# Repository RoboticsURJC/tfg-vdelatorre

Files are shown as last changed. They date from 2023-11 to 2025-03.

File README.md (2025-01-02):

# Repositorio de trabajo del TFG
# Víctor de la Torre Rosa

Como primera idea, este TFG estará enfocado a diseñar un prototipo de un
robot que pueda localizarse en interiores y que sea controlado por comandos por voz con el uso de una raspberry a un coste relativamente bajo.

## Material necesario:

[Raspberry PI 4 modelo B](https://www.amazon.es/Raspberry-Modelo-Cortex-A72-1-50GHz-Bluetooth/dp/B0CJ4XHZ4G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)  

[Micrófono micro USB](https://www.amazon.es/gp/product/B08BHM9VVW/ref=ox_sc_act_title_1?smid=A19HXCV96LJNAY&psc=1)

[Tarjeta micro SD](https://es.aliexpress.com/item/1005007985763599.html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)

[Controlador driver l298n](https://www.amazon.es/OcioDual-Controlador-Motores-Driver-Stepper/dp/B07YNR5KWP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)

[Rueda loca](https://www.planetaelectronico.com/rueda-loca-para-robot-diy-p-16998.html)

[Filamento PLA+ 1.75mm](https://www.amazon.es/SUNLU-PLA-3D-1-75mm-dimensional/dp/B07W47D4YZ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)

[Magnetómetro mpu9250](https://es.aliexpress.com/item/1005006375372078.html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)

[Batería recargable](https://www.amazon.es/Gecoty%C2%AE-Bater%C3%ADa-recargable-2400mAh-Conector/dp/B091232MQT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)

[Power Bank](https://www.amazon.es/SLuB-12000mAh-Bateria-Pantalla-Alimentaci%C3%B3n/dp/B0B4RWNZY3?th=1)

[Ruedas y motores reductores](https://www.amazon.es/HeyNana-Ruedas-Motores-Reductor-Coche/dp/B07LDP1DP9?th=1)

En cuanto al entorno de programación, la Raspberry tiene por defecto 
instalado Thonny Python IDE el cual es para proyectos más simples y tiene menos
capacidades que Python 3(IDLE), el cual es más conveniente para este tipo de 
proyectos. Para instalarlo:

```
sudo apt install python3 idle3
``` 

Revisar la [wiki](https://github.com/RoboticsURJC/tfg-vdelatorre/wiki) para más información sobre el proyecto.

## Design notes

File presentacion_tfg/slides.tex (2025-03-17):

% Completa los datos convenientemente en las zonas marcadas con TODO

\documentclass{beamer}
%PARA VISUALIZAR PRESENTACIONN CON NOTAS USAR VISUALIZADOR "pdfpc":
%Para ver las notas, el cronometro y siguente diapo:
% pdfpc --notes=right slides.pdf
% "tecla p": para pausar el cronometro
\mode<presentation> {
  \usetheme{CambridgeUS}
  \usecolortheme{crane} % color naranja
}
\setbeamercolor{titlelike}{parent=structure,bg=yellow!85!orange} % Cambia el color de la caja del título de la página inicial

\setbeamertemplate{navigation symbols}{} % ocultar iconos de navegación
\setbeamerfont{subsection in toc}{size=\small} % reducir tamaño en TOC
\setbeamerfont{date}{size=\tiny}
\usepackage[spanish]{babel}
\usepackage[utf8]{inputenc}
\usepackage{graphicx}
\usepackage{booktabs}
\usepackage{hyperref}
\usepackage{multicol}
\usepackage{pgfpages}
\usepackage{listings}
\usepackage{multimedia}
\usepackage[export]{adjustbox}
\usepackage{outlines} % Para poner bullets tabulados (\1 \2 \3 ...) y no items
\usepackage{fontawesome5} 
\usepackage{array,tabularx} % para tabular leyenda de ecuaciones
\newenvironment{conditions*} % entorno de "leyenda de ecuación"
  {\par\vspace{\abovedisplayskip}\noindent
   \tabularx{\columnwidth}{>{$}l<{$} @{\ : } >{\raggedright\arraybackslash}X}}
  {\endtabularx\par\vspace{\belowdisplayskip}}
  
% USO DE NOTAS
\setbeameroption{hide notes} % Para mostrar u ocultar (hide/show)
%\setbeameroption{show only notes} % Mostrar solo las notas
%\setbeameroption{show notes on second screen=right} % Mostrar notas en otra pantalla
\setbeamertemplate{note page}{ % asi solo muestro el texto de las notas
  \insertnote%
}

%========= TODO: datos internos del documento
\hypersetup{
	pdftitle={Defensa de trabajo de fin de grado de Pon tu nombre},
	pdfauthor={Pon tu nombre},
	pdfsubject={Pon aquí el título completo del trabajo},
	pdfkeywords={teaching, robotics, vision, sensors, actuators, raspberry},
	pdfproducer={pdfLaTeX},
  colorlinks=true,
  linkcolor=blue
}
%=========

%========= TODO: diapositiva de portada
\title[Robot de bajo coste guiado por voz]{Prototipo de robot de bajo coste guiado por voz con técnicas de localización} % El título reducido aparece en la parte inferior de todas las diapositivas
                                         % El título completo aparece solo en la diapositiva de portada
\author[Víctor de la Torre Rosa]{Víctor de la Torre Rosa}
\institute[URJC]
{
\textit{\href{mailto:escribe.tu@correo.es}{\color{blue}{\underline{v.delatorre.2019@alumnos.urjc.es}}}}\\
\vspace{0.5cm}
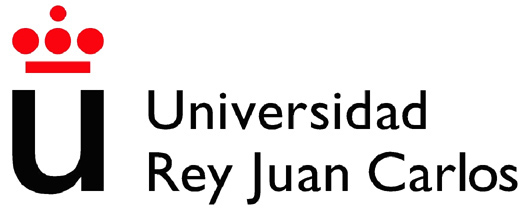
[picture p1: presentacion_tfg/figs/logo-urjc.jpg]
\\
\vspace{1cm}
Trabajo Fin de Grado
}
\date{18 de marzo de 2025}
%=========

%========= COMIENZO DEL DOCUMENTO
\begin{document}

%========= Portada inicial con notas
\begin{frame}[plain] % plain: quita header y footer
\large{\titlepage}
\note[item]{En esta presentación voy a hablar sobre...}
\note[item]{En primer lugar...}
\end{frame}

%========= Licencia
\begin{frame}
\input{licencia.tex}
\end{frame}

%========= Índice o tabla de contenidos (TOC)
\begin{frame}
\frametitle{Contenidos}
\begin{multicols}{2} % si tengo muchas secciones, lo parte en dos columnas
  \tableofcontents[hideallsubsections] % no muestra subsecciones
\end{multicols}
\note[item]{La presentaci\'on esta dividida en cuatro partes.}
\end{frame}

%========= Diapositiva "vacía" de comienzo de sección:
\section*{}
\begin{frame}{}
  \centering \Huge
  \emph{Introducción}
\note[item]{Comencemos con la introducción.}
\end{frame}

\section{Introducción}
\subsection{Contexto general}
%========= Diapositiva con imágenes:
\begin{frame}
\frametitle{Robótica móvil}
\centering
\begin{minipage}{0.45\textwidth}
    \centering
    
\end{minipage}
\hfill
\begin{minipage}{0.45\textwidth}
    \centering
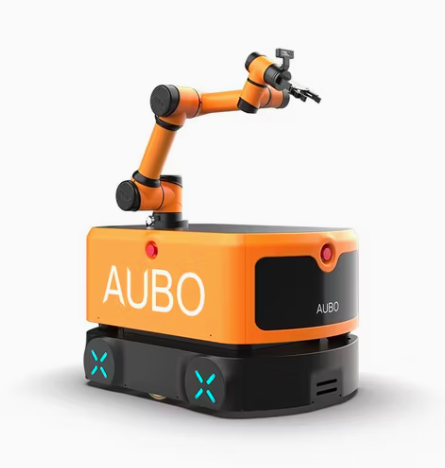
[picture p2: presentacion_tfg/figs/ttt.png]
    
\end{minipage}
\end{frame}

%========= Diapositiva con ítems resaltados con colores:
\begin{frame}
\frametitle{Robótica educativa y de bajo coste}
\centering

% Primera fila
\begin{minipage}{0.45\textwidth}
    \centering
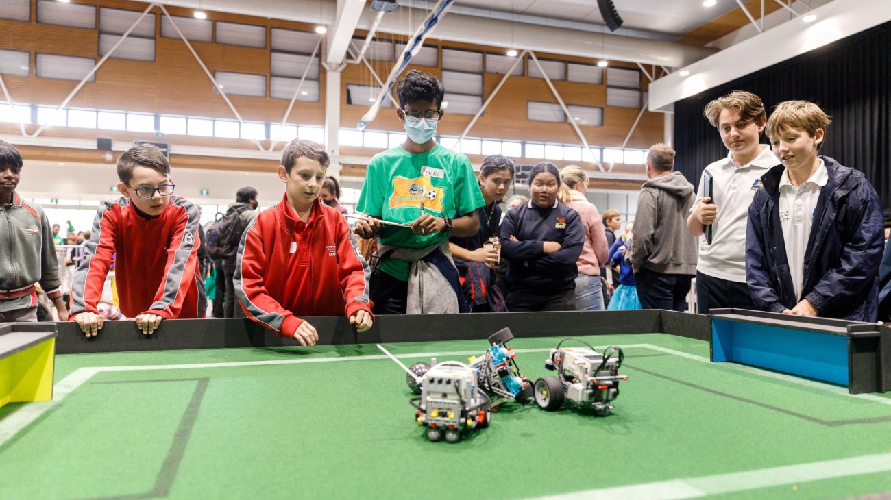
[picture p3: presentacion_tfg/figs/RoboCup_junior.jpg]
    
\end{minipage}
\hfill
\begin{minipage}{0.45\textwidth}
    \centering
    
\end{minipage}

\vspace{0.5cm} % Espacio entre filas

% Segunda fila
\begin{minipage}{0.45\textwidth}
    \centering
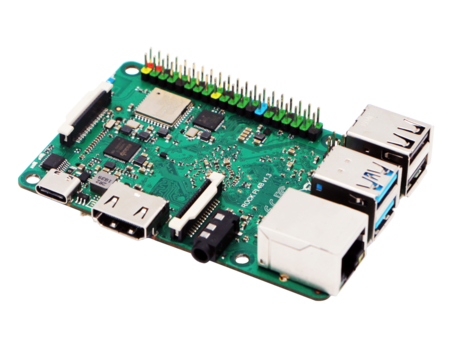
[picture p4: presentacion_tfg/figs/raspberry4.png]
     % Cambia por la ruta de la tercera imagen
\end{minipage}
\hfill
\begin{minipage}{0.45\textwidth}
    \centering
     % Cambia por la ruta de la cuarta imagen
\end{minipage}

\end{frame}

\section*{}
\begin{frame}{}
  \centering \Huge
  \emph{Objetivos}
\note[item]{Pasemos ahora a comentar los objetivos que nos hemos con este trabajo.}
\end{frame}

\section{Objetivos}
\begin{frame}
\frametitle{Descripción del problema}
\centering

% Primera fila
\begin{minipage}{0.45\textwidth}
    \centering
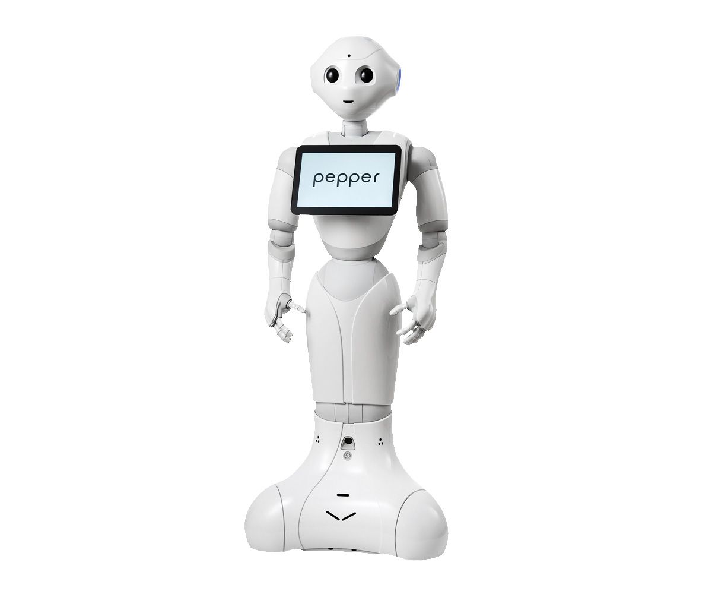
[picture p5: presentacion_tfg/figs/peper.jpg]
    
\end{minipage}
\hfill
\begin{minipage}{0.45\textwidth}
    \centering
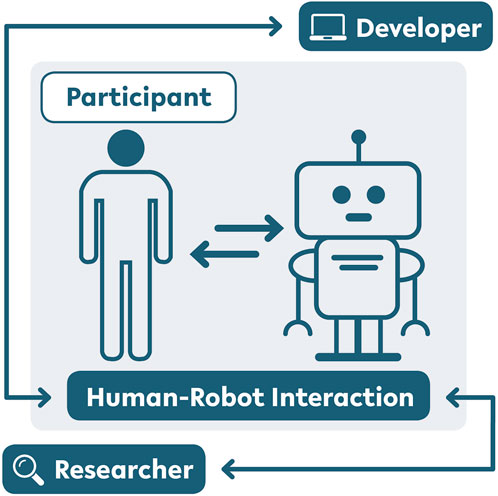
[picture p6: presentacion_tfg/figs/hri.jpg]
    
\end{minipage}

\vspace{0.5cm} % Espacio entre filas

% Segunda fila
\begin{minipage}{0.45\textwidth}
    \centering
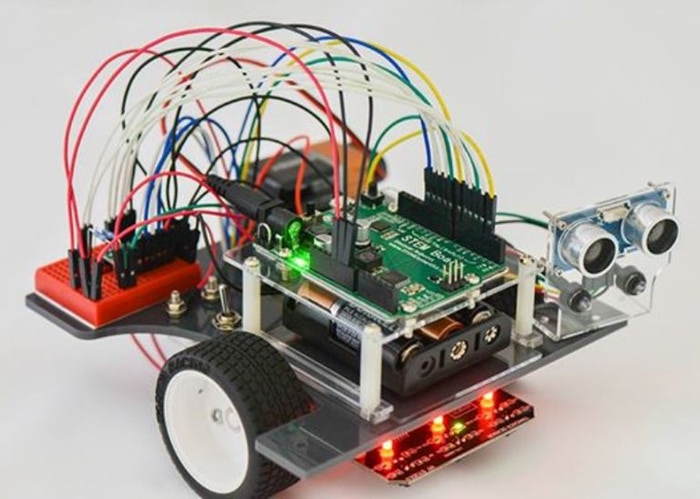
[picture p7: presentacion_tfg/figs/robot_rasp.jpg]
     % Cambia por la ruta de la tercera imagen
\end{minipage}
\hfill
\begin{minipage}{0.45\textwidth}
    \centering
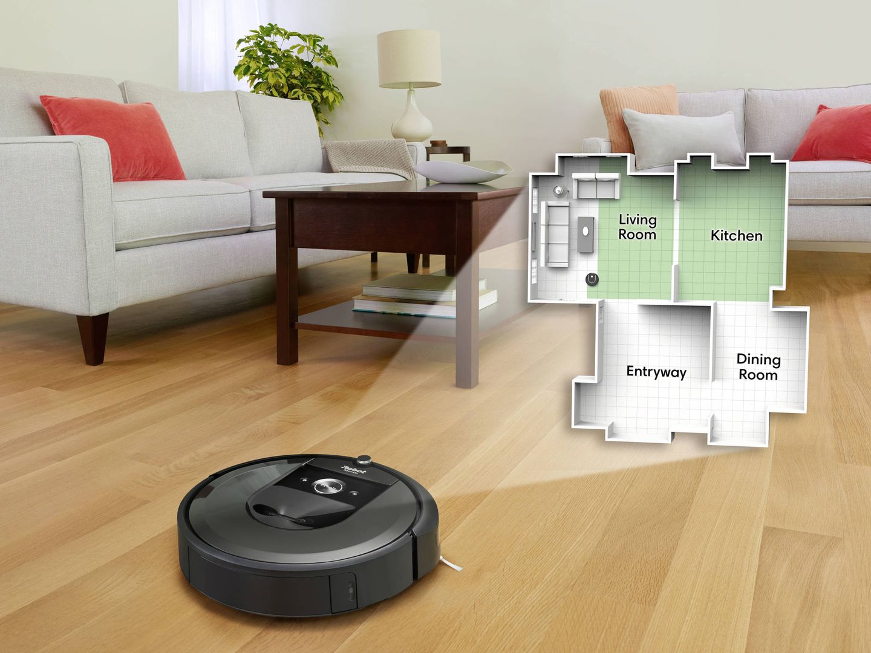
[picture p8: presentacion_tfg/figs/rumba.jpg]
     % Cambia por la ruta de la cuarta imagen
\end{minipage}

\end{frame}

\begin{frame}
\frametitle{Requisitos}
\begin{enumerate}
    \item 145€.
    \item \faDollarSign
    \item \faWifi % Ícono de Wi-Fi en lugar de texto
    \item Impresora convencional 3D.
    \item Tiempo real.
    \item Python.
    \item Batería recargable.
    \item Peso ligero.
\end{enumerate}
\end{frame}

\begin{frame}
\frametitle{Objetivos específicos}
\begin{enumerate}
\item Diseño.
\item Estado del arte.
\item Control del robot.
\item Navegación + Localización.
\item Calibración.
\item Red neuronal.
\end{enumerate}
\end{frame}

\begin{frame}
\frametitle{Metodología}
\centering
\begin{minipage}{0.45\textwidth}
    \centering
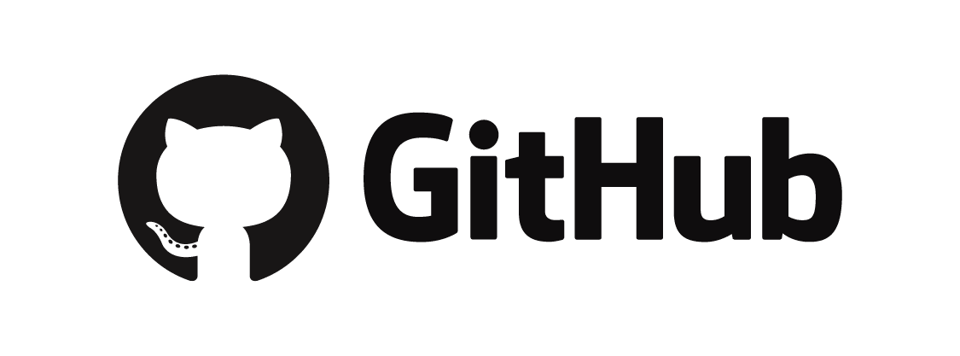
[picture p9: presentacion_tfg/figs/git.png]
    
\end{minipage}
\hfill
\begin{minipage}{0.45\textwidth}
    \centering
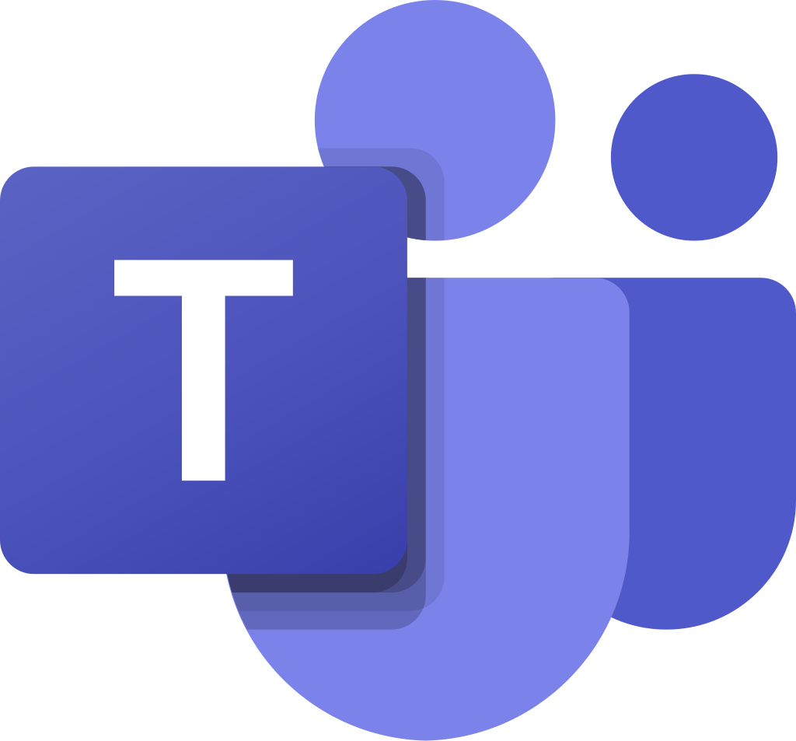
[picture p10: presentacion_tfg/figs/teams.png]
    
\end{minipage}
\vfill

\href{https://github.com/RoboticsURJC/tfg-vdelatorre}{https://github.com/RoboticsURJC/tfg-vdelatorre}
\end{frame}

\section*{}
\begin{frame}{}
  \centering \Huge
  \emph{Plataforma de desarrollo}
\note[item]{Una vez descritos los objetivos, veamos qué hemos hecho para alcanzarlos.}
\end{frame}

\section{Plataforma de desarrollo}
\begin{frame}
\frametitle{Hardware}
\centering

% Primera fila
\begin{minipage}{0.3\textwidth}
    \centering
    
\end{minipage}
\hfill
\begin{minipage}{0.3\textwidth}
    \centering
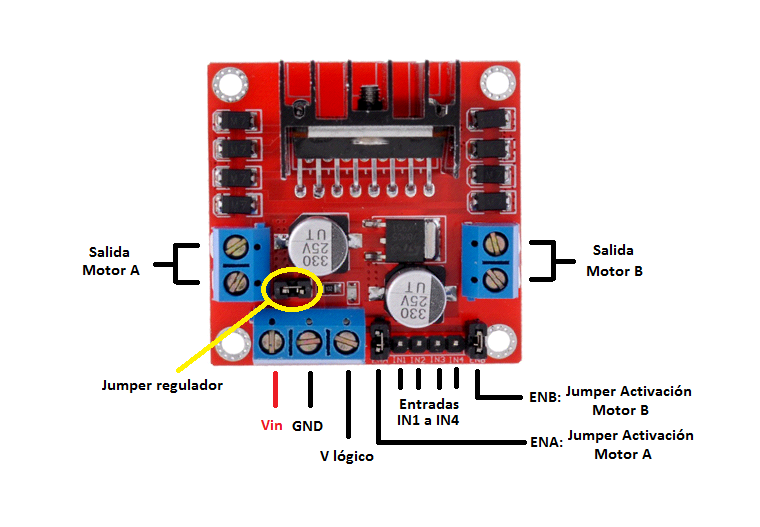
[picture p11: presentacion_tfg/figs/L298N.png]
    
\end{minipage}
\hfill
\begin{minipage}{0.3\textwidth}
    \centering
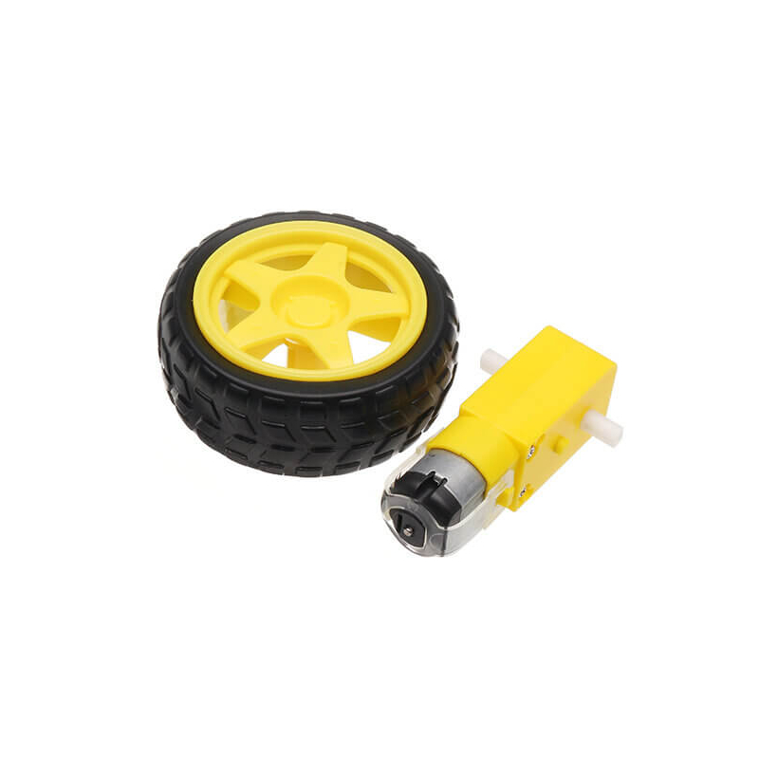
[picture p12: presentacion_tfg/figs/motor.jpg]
    
\end{minipage}

\vspace{-0.3cm} % Reduce el espacio entre filas

% Segunda fila
\begin{minipage}{0.3\textwidth}
    \centering
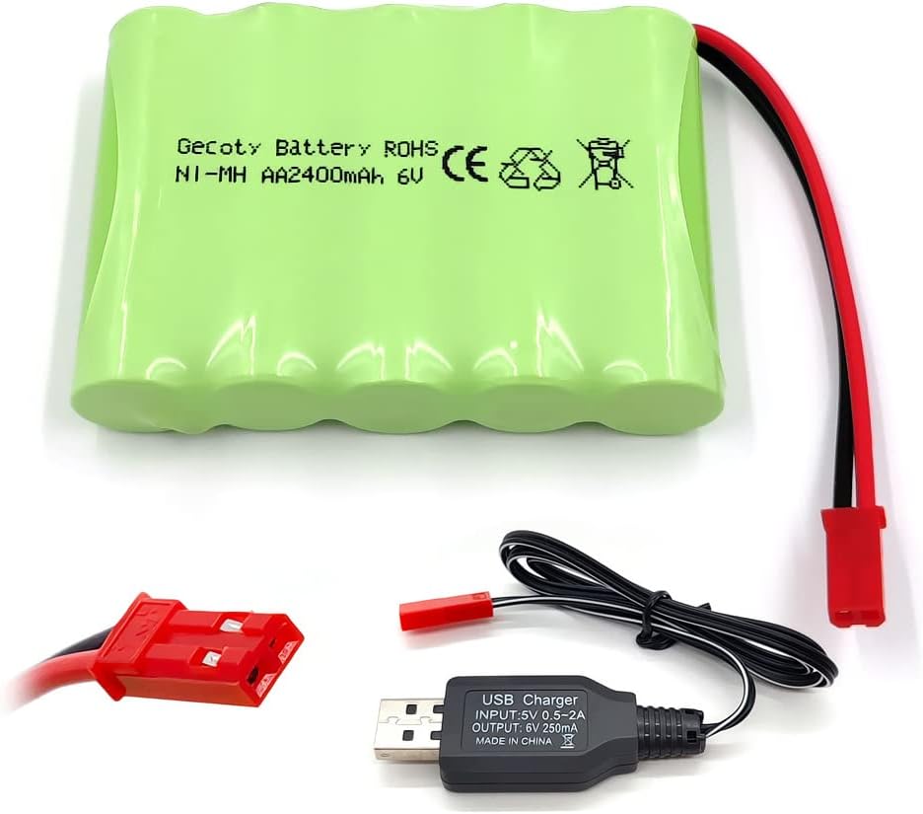
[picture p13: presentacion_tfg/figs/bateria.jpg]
     
\end{minipage}
\hfill
\begin{minipage}{0.3\textwidth}
    \centering
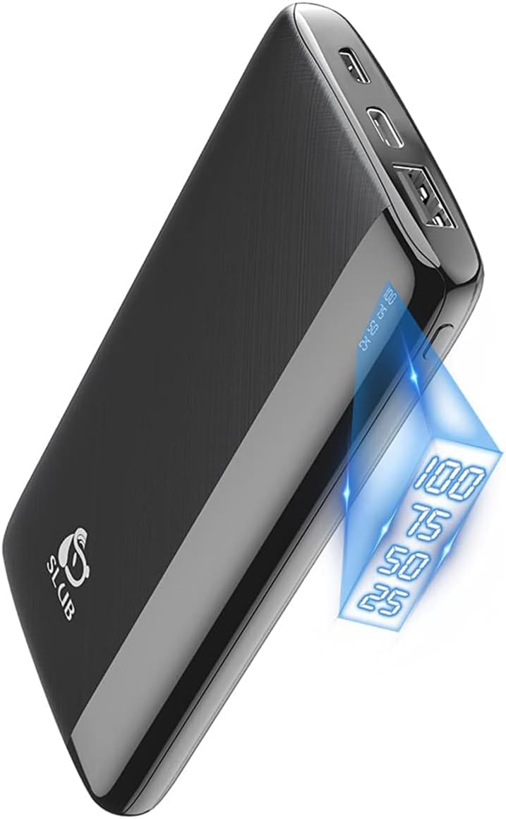
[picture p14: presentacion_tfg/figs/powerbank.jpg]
     
\end{minipage}
\hfill
\begin{minipage}{0.3\textwidth}
    \centering
    
\end{minipage}

% Tercera fila
\begin{minipage}{0.3\textwidth}
    \centering
     
\end{minipage}
\hfill
\begin{minipage}{0.3\textwidth}
    \centering
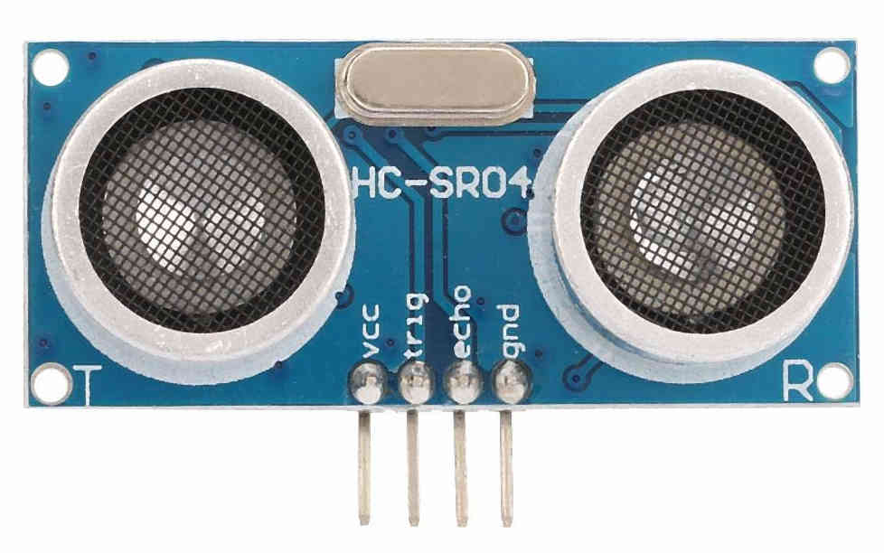
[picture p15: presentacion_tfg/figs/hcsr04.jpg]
     
\end{minipage}
\hfill
\begin{minipage}{0.3\textwidth}
    \centering
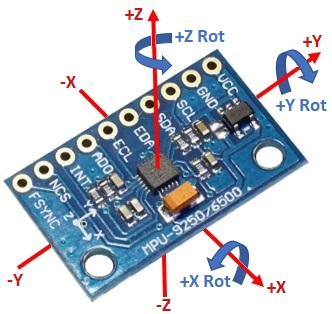
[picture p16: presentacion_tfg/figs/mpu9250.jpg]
    
\end{minipage}

\vspace{-0.5cm} % Reduce el espacio entre filas

% Imagen centrada en la última fila
\begin{center}
    
\end{center}

\end{frame}

%========= Diapositiva con matemáticas y leyenda (conditions*):
\begin{frame}
\frametitle{Software}

\centering

% Primera fila
\begin{minipage}{0.3\textwidth}
    \centering
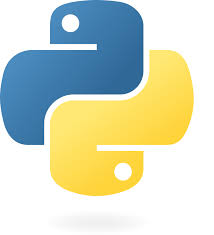
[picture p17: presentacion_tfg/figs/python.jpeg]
    
\end{minipage}
\hfill
\begin{minipage}{0.3\textwidth}
    \centering
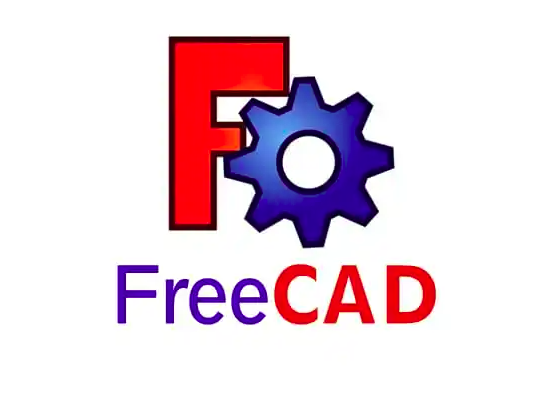
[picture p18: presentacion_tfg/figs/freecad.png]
    
\end{minipage}
\hfill
\begin{minipage}{0.3\textwidth}
    \centering
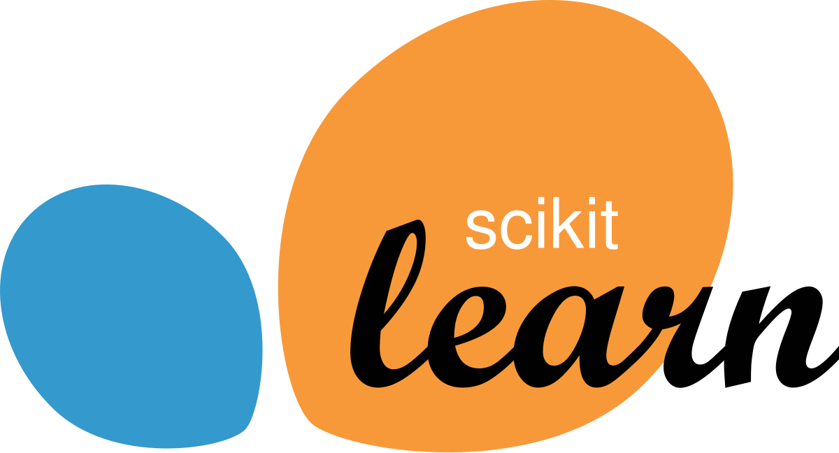
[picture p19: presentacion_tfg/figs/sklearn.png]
    
\end{minipage}

\vspace{0.3cm} % Reduce el espacio entre filas

% Segunda fila
\begin{minipage}{0.3\textwidth}
    \centering
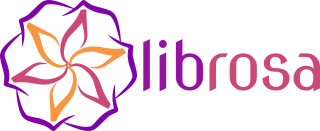
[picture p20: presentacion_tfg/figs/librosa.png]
     
\end{minipage}
\hfill
\begin{minipage}{0.3\textwidth}
    \centering
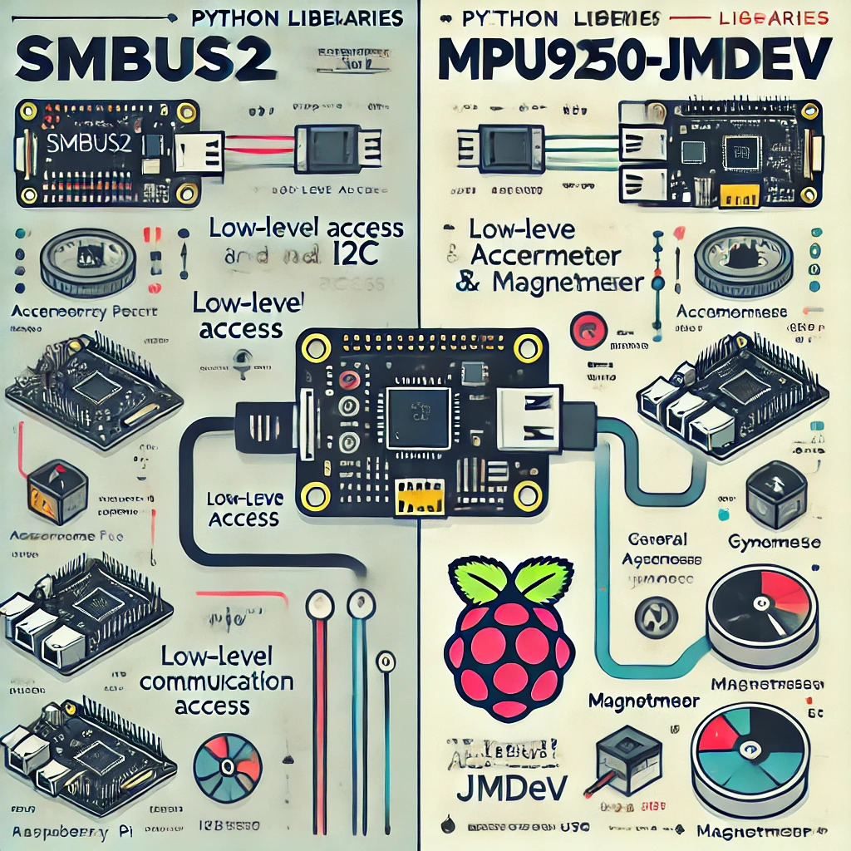
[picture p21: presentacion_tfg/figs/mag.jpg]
     
\end{minipage}
\hfill
\begin{minipage}{0.3\textwidth}
    \centering
    
\end{minipage}
% Tercera fila
\begin{minipage}{0.3\textwidth}
    \centering
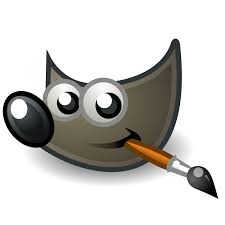
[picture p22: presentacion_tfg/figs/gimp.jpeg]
     
\end{minipage}
\end{frame}

\section*{}
\begin{frame}{}
  \centering \Huge
  \emph{Arquitectura hardware}
\note[item]{Una vez descritos los objetivos, veamos qué hemos hecho para alcanzarlos.}
\end{frame}

\section{Arquitectura hardware}
\begin{frame}
\frametitle{Geometría del robot}
\centering
\begin{minipage}{0.45\textwidth}
    \centering
    
\end{minipage}
\hfill
\begin{minipage}{0.45\textwidth}
    \centering
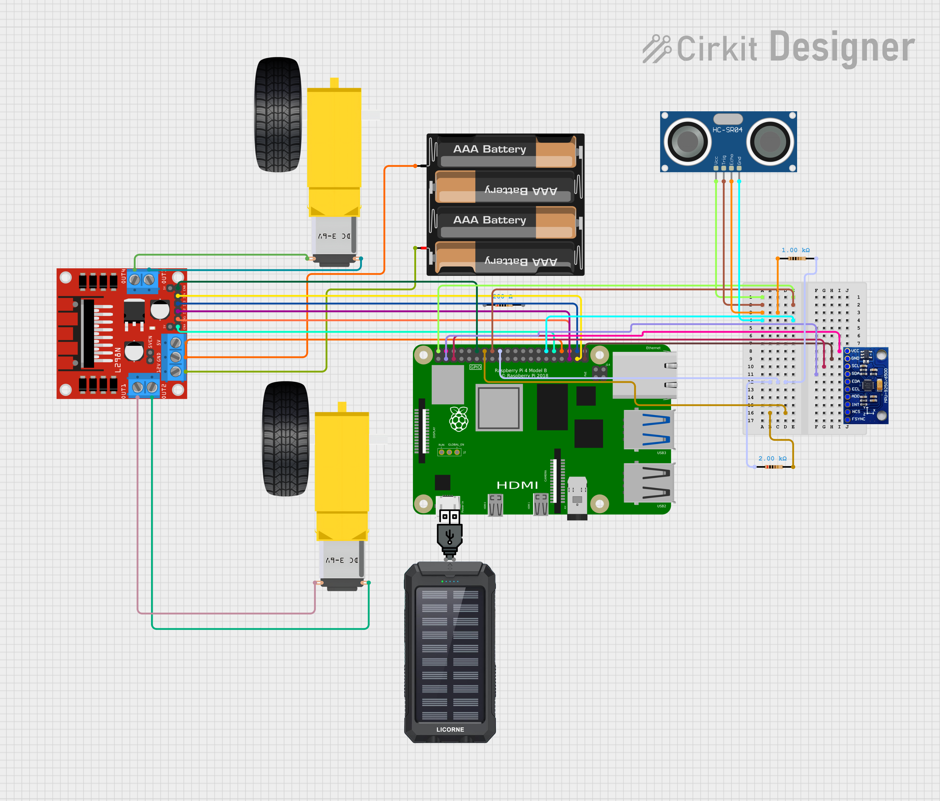
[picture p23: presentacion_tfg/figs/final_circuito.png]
    
\end{minipage}

\end{frame}

\begin{frame}
\frametitle{Geometría del robot}
\centering
\begin{minipage}{0.45\textwidth}
    \centering
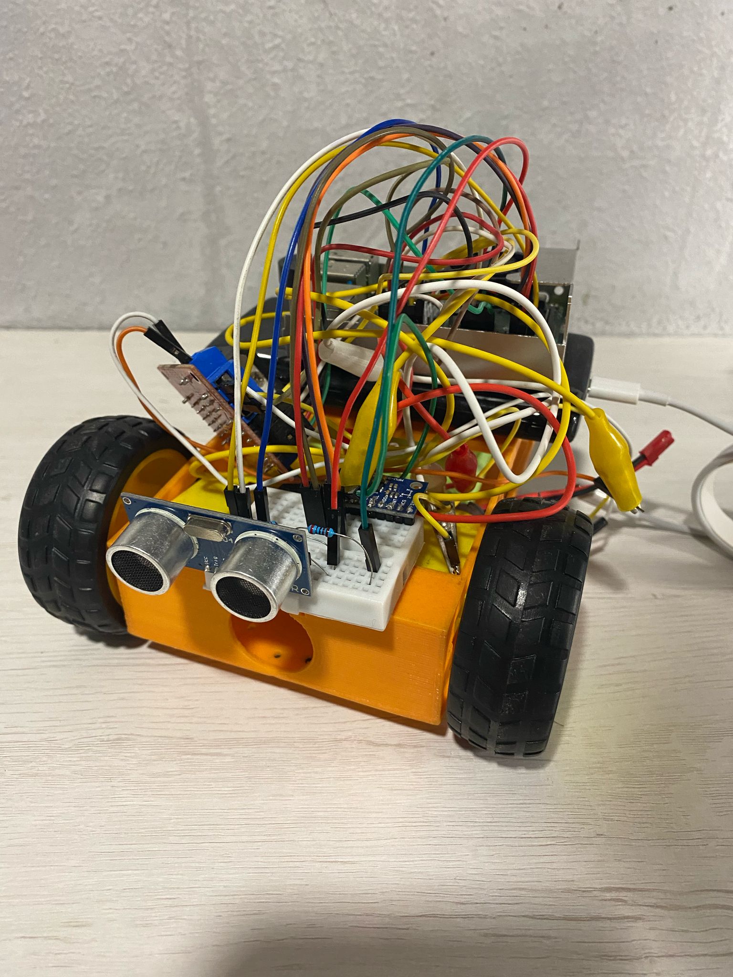
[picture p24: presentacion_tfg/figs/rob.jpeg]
    
\end{minipage}

\end{frame}

\section*{}
\begin{frame}{}
  \centering \Huge
  \emph{Desarrollo software}
\end{frame}

\section{Desarrollo software}
\begin{frame}
\frametitle{Orientación y diseño del mapa}
\centering
\begin{minipage}{0.45\textwidth}
    \centering
    
\end{minipage}
\hfill
\begin{minipage}{0.45\textwidth}
    \centering
    
\end{minipage}
\hfill
\vspace{0.3cm} % Reduce el espacio entre filas
\begin{minipage}{0.45\textwidth}
    \centering
    
\end{minipage}

\end{frame}

\begin{frame}
\frametitle{Interfaz de usuario}
\centering
\begin{minipage}{0.45\textwidth}
    \centering
    
\end{minipage}
\hfill
\begin{minipage}{0.45\textwidth}
    \centering
    
\end{minipage}
\hfill
\vspace{0.3cm} % Reduce el espacio entre filas
\begin{minipage}{0.45\textwidth}
    \centering
    
\end{minipage}
\hfill
\begin{minipage}{0.45\textwidth}
    \centering
    
\end{minipage}
\hfill
\vspace{0.3cm} % Reduce el espacio entre filas
\begin{minipage}{0.45\textwidth}
    \centering
    
\end{minipage}

\end{frame}

\begin{frame}
\frametitle{Localización}
\centering
\begin{minipage}{0.45\textwidth}
    \centering
    
\end{minipage}

\end{frame}

\begin{frame}
\frametitle{Localización}
\centering

\begin{equation}
d = 10^{\frac{A - \texttt{RSSI}}{10 \cdot n}}
\label{ec:ec2}
\end{equation}
\texttt{Donde:}
\begin{itemize}
    \item $d$: Distancia estimada en metros.
    \item $A$: Valor RSSI a 1 metro del AP.
    \item \texttt{RSSI}: Potencia recibida.
    \item $n$: Factor de propagación.
\end{itemize}
\vspace{0.3cm} % Reduce el espacio entre filas
\begin{equation}
\left\{
	\begin{array}{lcc}
		(x - x_1)^2 + (y - y_1)^2 = (d_1)^2\\
		(x - x_2)^2 + (y - y_2)^2 = (d_2)^2\\
		(x - x_3)^2 + (y - y_3)^2 = (d_3)^2 \\
		(x - x_4)^2 + (y - y_4)^2 = (d_4)^2
	\end{array}
\right.
\label{ec:ec5}
\end{equation}

\end{frame}

\begin{frame}
\frametitle{Navegación (A*)}
\centering

\begin{minipage}{0.45\textwidth}
    \centering
    
\end{minipage}

\vspace{-0.6cm} % Reduce el espacio entre filas
\begin{equation}
\left\{
	f(n) = g(n) + h(n)
\right.
\label{ec:ec678}
\end{equation}

\texttt{Donde:}
\begin{itemize}
    \item $g(n)$: Coste de cada movimiento.
    \item $h(n)$: Heurística.
\end{itemize}

\end{frame}

\section*{}
\begin{frame}{}
  \centering \Huge
  \emph{Pruebas y experimentos}
\end{frame}

\section{Pruebas y experimentos}
\begin{frame}
\frametitle{Calibración magnética}
\centering

% Primera fila
\begin{minipage}{0.45\textwidth}
    \centering
    
\end{minipage}
\hfill
\begin{minipage}{0.45\textwidth}
    \centering
    
\end{minipage}

\vspace{0.5cm} % Espacio entre filas

% Segunda fila
\begin{minipage}{0.7\textwidth}
    \centering
     % Cambia por la ruta de la tercera imagen
\end{minipage}
\hfill

\end{frame}

\begin{frame}
\frametitle{Elección del modelo de aprendizaje automático}
\centering

\centering

\begin{table}[H]
\begin{center}
\begin{tabular}{|c|c|c|c|c|}
\hline
\textbf{Classifier} & \textbf{Accuracy Score}\\
\hline
KNeighborsClassifier & 93.75\%  \\  
SVC & 100.00\%  \\
SVC RBF kernel & 93.75\%  \\
DecisionTreeClassifier & 87.50\%  \\
RandomForestClassifier & 100.00\%  \\
AdaBoostClassifier & 43.75\%  \\
GaussianNB & 93.75\%  \\
QuadraticDiscriminantAnalysis & 31.25\  \\
MLPClassifier & 93.75\%  \\
\hline
\end{tabular}
\label{cuadro:tabla2}
\end{center}
\end{table}

\end{frame}

\begin{frame}
\frametitle{Elección del número de APs}
\centering

% Primera fila
\begin{minipage}{0.45\textwidth}
    \centering
    
\end{minipage}
\hfill
\begin{minipage}{0.45\textwidth}
    \centering
    
\end{minipage}

\vspace{0.3cm} % Espacio entre filas

% Segunda fila
\begin{minipage}{0.45\textwidth}
    \centering
     % Cambia por la ruta de la tercera imagen
\end{minipage}
\hfill
\begin{minipage}{0.45\textwidth}
    \centering
     % Cambia por la ruta de la cuarta imagen
\end{minipage}

\end{frame}

\begin{frame}
\frametitle{Elección del número de APs}
\centering

\begin{table}[H]
\begin{center}
\begin{tabular}{|c|c|c|c|c|}
\hline
\textbf{Nodos} & \textbf{SVC, Linear} & \textbf{SVC,RBF} & \textbf{DTREE} & \textbf{RF} \\
\hline
2 & 28\% & 31\% & 28\% & 24\% \\  
3 & 82\% & 86\% & 78\% & 82\% \\   
4 & 94\% & 94\% & 91\% & 94\% \\   
\hline
\end{tabular}
\label{cuadro:tabla2}
\end{center}
\end{table}

\begin{table}[H]
\begin{center}
\begin{tabular}{|c|c|c|c|c|}
\hline
\textbf{Nodos} & \textbf{SVC, Linear} & \textbf{SVC,RBF} & \textbf{DTREE} & \textbf{RF} \\
\hline
4 & 99\% & 99\% & 96\% & 100\% \\  
\hline
\end{tabular}
\label{cuadro:tabla3}
\end{center}
\end{table}

% Primera fila
\begin{minipage}{0.45\textwidth}
    \centering
    
\end{minipage}
\hfill
\begin{minipage}{0.45\textwidth}
    \centering
    
\end{minipage}

\vspace{0.3cm} % Espacio entre filas
\end{frame}

\section*{}
\begin{frame}{}
  \centering \Huge
  \emph{Conclusiones}
\end{frame}

\section{Conclusiones}
\begin{frame}
\begin{block}{Objetivos cumplidos}
\begin{itemize}
\item Robot móvil de bajo coste.
\item CPU de baja capacidad de cómputo.
\item Navegación, orientación y localización en interiores.
\item Portabilidad.
\item Comunicación.
\end{itemize}

\begin{itemize}
\item \href{https://youtube.com/shorts/wm4-3SVO6g4?feature=share}{https://youtube.com/shorts/wm4-3SVO6g4?feature=share}
\item \href{https://youtube.com/shorts/i80oPc5RJ9w?feature=share}{https://youtube.com/shorts/i80oPc5RJ9w?feature=share}
\end{itemize} 

\end{block}

\end{frame}

\begin{frame}
\begin{block}{Líneas futuras}
\begin{itemize}
\item Aumentar datos de entrenamiento.
\item Smartphones.
\item Áreas de mayor tamaño y más dispositivos Wi-Fi.
\item Altavoz.
\item Nuevas rutas.
\end{itemize}
\end{block}
\end{frame}

\begin{frame}[plain]
\large{\titlepage}
\note[item]{Y hasta aquí mi exposición.}
\note[item]{Quedo a disposición del tribunal...}
\end{frame}

\end{document}

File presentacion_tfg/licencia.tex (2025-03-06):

% Este diseño se corresponde con la licencia CC-BY-NC-SA.
% Por supuesto, puedes poner la licencia que mejor se adapte al propósito de tu trabajo.
% Recuerda que, si no se especifica ninguna licencia, esta -como cualquier creación artística- pasaría a estar licenciada con todos los derechos reservados (copyright).

\vspace{5cm}

\begin{flushright}

\begin{figure}

\end{figure}

\vspace{0.2cm}

{\tiny 
(CC) \textbf{Víctor de la Torre Rosa}\\ % TODO: pon aquí tu nombre cuando hagas el documento
\vspace{0.5cm}
\emph{
Este trabajo se entrega bajo licencia \href{https://creativecommons.org/licenses/by-nc-sa/3.0/es/}{CC BY-NC-SA}. \\
Usted es libre de \textit{(a) compartir}: copiar y redistribuir el material en \\
cualquier medio o formato; y \textit{(b) adaptar}: remezclar, transformar \\
y crear a partir del material. El licenciador no puede revocar estas \\
libertades mientras cumpla con los términos de la licencia. \\}
}

\end{flushright}

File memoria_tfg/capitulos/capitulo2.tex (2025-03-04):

\chapter{Estado del arte}
\label{cap:capitulo2}
\setcounter{page}{1}

\begin{flushright}
\begin{minipage}[]{10cm}
\emph{Eres el amo de tu destino, el capitán de tu alma.}\\
\end{minipage}\\

Napoleon Hill, \textit{Piense y hágase rico}\\
\end{flushright}

\vspace{1cm}

En este capítulo se definirán algunos de los trabajos que han tenido más importancia en este proyecto. Se han revisado diferentes áreas con el propósito de comprender y aplicar conceptos clave en la creación del sistema; como el control de motores a través de señales \hyperlink{PWM}{PWM} (Pulse Width Modulation), una interfaz \hyperlink{HRI}{HRI} amena para poder comunicarse con el robot, modelos de aprendizaje automático para el reconocimiento de órdenes mediante comandos de voz, posicionamiento en interiores a partir de señales de \hyperlink{RSSI}{RSSI} (Received Signal Strength Indicator), y algoritmos de planificación de rutas para navegar en interiores.\\

En \cite{9815716} se presentan diferentes alternativas sobre cómo controlar motores de corriente continua mediante señales \hyperlink{PWM}{PWM} a los microcircuitos o, en este caso, motores reductores mediante un módulo controlador de motor L298N que puede regular la velocidad y la dirección en ambos sentidos de los motores al mismo tiempo, lo cual es muy importante, ya que de esta manera no haría falta sincronizar ambos motores.\\

Por otra parte, se necesitará averiguar qué modelo de aprendizaje automático (Figura \ref{fig:random_forest}) es el ideal para poder clasificar correctamente comandos por voz en diferentes clases, lo cual es fundamental para desarrollar una interfaz \hyperlink{HRI}{HRI} amena que permita una comunicación efectiva con el robot. Esto se presenta en \cite{Zenkov-sklearn-SER-basics}, donde se ofrecen diferentes técnicas que se pueden aplicar a problemas de clasificación, regresión y técnicas de ingeniería de características para datos de audio. Además, se ofrece un vistazo en profundidad a la lógica, los conceptos y las propiedades de las redes neuronales profundas actuales, proporcionando información clave sobre algunos modelos de aprendizaje automático y la lógica en la elección de sus hiperparámetros, cuyo objetivo es reconocer comandos de audio por voz, permitiendo al robot comprender y ejecutar órdenes dadas por el usuario.\\

\begin{figure} [H]
  \begin{center}
    
  \end{center}
  \caption{Algoritmo de aprendizaje automático Random forest.}
  \label{fig:random_forest}
\end{figure}\

De manera similar, el aprendizaje automático también desempeña un papel fundamental en la localización interna del robot, donde se emplean técnicas avanzadas para estimar su posición precisa en entornos interiores. Para poder determinar la posición precisa del robot, es necesario hacer uso de técnicas de localización interna. En este otro artículo \cite{unknown} se realiza un estudio sobre los sistemas de posicionamiento en interiores de ``fingerprinting"(Figura \ref{fig:wifi}) que utiliza modelos de aprendizaje automático para crear un mapa de ubicación \hyperlink{RSSI}{RSSI} del entorno para una mejor estimación de la ubicación y que a diferencia de los sistemas de posicionamiento en interiores \hyperlink{BLE}{BLE} (Bluetooth Low Energy) que se han implementado con modelos de pérdida de propagación, los cuales han demostrado estimar posiciones con grandes errores debido a la incertidumbre de las señales \hyperlink{RSSI}{RSSI} causadas por obstáculos en interiores y fenómenos electromagnéticos, los de fingerprinting consiguen una mejor estimación de la posición. Para demostrarlo, se probarán diferentes hipótesis, como las siguientes:

\begin{enumerate}
 \item ¿La precisión de las balizas \hyperlink{BLE}{BLE} escala linealmente con la cantidad de las mismas?
 \item ¿La precisión aumenta
cuando la distancia mínima entre dos posiciones es de 1 m mientras que el área de mapeo no cambia?
\end{enumerate}\ 

\begin{figure} [H]
  \begin{center}
    
  \end{center}
  \caption{Principio de WiFi fingerprinting.}
  \label{fig:wifi}
\end{figure}\

Los resultados de ambas hipótesis fueron verdaderas, por lo que para este proyecto servirá de gran ayuda para saber con precisión cuántos puntos de acceso WiFi son necesarios para un entorno. En este caso no se usarán balizas Bluetooth pero el procedimiento sería el mismo. Para poder estimar la posición del robot en el mapa mediante balizas WiFi, se hará uso de la trilateración (Figura \ref{fig:trilateration}), la cual es una técnica presentada y estudiada en el artículo \cite{inproceedings}. En él, se presenta un método basado en WiFi para el posicionamiento en interiores utilizando mediciones de intensidad de señal recibida (\hyperlink{RSSI}{RSSI}). También se estiman las distancias entre los Access Points (\hyperlink{APs}{APs}) y el dispositivo móvil a partir de valores \hyperlink{RSSI}{RSSI} evaluados por el modelo de propagación de la señal. Esto servirá para calcular, mediante diferentes fórmulas, la posición del robot en el mapa conociendo a su vez la posición de las balizas y ver cuánto error hay en la estimación.\\

\begin{figure} [H]
  \begin{center}
    
  \end{center}
  \caption{Técnica de trilateración por WiFi.}
  \label{fig:trilateration}
\end{figure}\

Una vez conocida la posición del robot, es importante que pueda planificar la ruta de manera eficiente en el entorno. Para ello, los algoritmos de planificación de rutas juegan un papel esencial. Este artículo \cite{article} sirve como introducción al concepto de planificación de rutas y navegación en el contexto de la robótica, presentando algoritmos y casos de uso donde los especialistas en robótica pueden desarrollar aplicaciones de búsqueda o planificación de rutas. En ese artículo, también se describen las características del algoritmo de búsqueda A* (Figura \ref{fig:astar}) y sus aplicaciones para un sistema de navegación para vehículos robóticos, y es el que se usará en este trabajo por su optimización, precisión y eficiencia en tiempo de ejecución.

\begin{figure} [H]
  \begin{center}
    
  \end{center}
  \caption{Algoritmo de búsqueda A*.}
  \label{fig:astar}
\end{figure}\

Una vez establecido el sistema de planificación de rutas, el robot debe saber cómo desplazarse por la misma, siendo capaz de desplazarse en línea recta y de localizarse, pero se tienen en cuenta los giros que debe hacer en la ruta, por lo que se hará uso de un magnetómetro para conocer el ángulo de orientación del robot y así hacer giros más precisos. Otro paso importante, como se puede apreciar en \cite{Ozyagcilar2015}, son las diferentes técnicas para la calibración del sensor, en el cual se proporciona la teoría para la calibración de una brújula electrónica de un teléfono inteligente para mitigar los efectos de \textit{hard-iron} y \textit{soft-iron}, los cuales son los efectos producidos por materiales ferromagnéticos y que pueden magnetizarse sobre el magnetómetro.\\

Para poder garantizar que las lecturas del magnetómetro sean correctas y precisas y no se vean afectadas por ruidos o fluctuaciones, también sería necesario entender el uso de un filtro de paso bajo, como se explica en el artículo \cite{low_pass_filter}. Este filtro es fácil de implementar ya que utiliza pocos recursos y, con dos parámetros fáciles de entender, resulta fácil de ajustar. A diferencia de otros filtros, este tiene menos desfase, lo cual lo convierte en una buena opción para suavizar las lecturas del magnetómetro y permitir que el robot realice giros mucho más precisos.\\

Dado que el correcto procesamiento de los datos del magnetómetro, así como de otros sensores, depende en gran parte de la configuración del software y hardware utilizados, en el siguiente capítulo se detallan los elementos empleados en el desarrollo del sistema y se describen las librerías, sistemas operativos, plataformas y entornos de desarrollo utilizados, explicando su función y el motivo de su elección para el correcto funcionamiento del sistema.

\vspace{15cm} % Espacio vertical de 1 cm

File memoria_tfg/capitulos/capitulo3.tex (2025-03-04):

\chapter{Objetivos}
\label{cap:capitulo3}

\begin{flushright}
\begin{minipage}[]{10cm}
\emph{La proactividad es la clave para el éxito}\\
\end{minipage}\\

Stephen R. Covey, \textit{Los 7 hábitos de la gente altamente efectiva}\\
\end{flushright}

\vspace{1cm}

Una vez revisado el estado del arte correspondiente a este trabajo, se presenta el plan de trabajo de este, definiendo los 
objetivos que se han marcado, tanto específicos como generales, para poder desarrollar este proyecto, y los requisitos necesarios para el mismo.
Finalmente, se explica la metodología que se ha seguido para poder cumplir los objetivos propuestos.

\section{Descripción del problema}
\label{sec:descripcion}

El objetivo general de este proyecto es el desarrollo y diseño de un prototipo de robot guía de bajo coste, con el fin de ofrecer una solución más accesible y asequible frente a los robots guía convencionales, los cuales son generalmente caros y difíciles de adaptar a diferentes entornos debido a todos los cambios que serían necesarios a nivel de software. El sistema se diseñará para maximizar la eficiencia con los recursos disponibles, garantizando un equilibrio entre coste y funcionalidad. Esto llevará a soluciones innovadoras en el diseño del hardware y la optimización del software, permitiendo que el robot sea viable sin necesidad de componentes de alto coste. Este robot, mediante una interfaz \hyperlink{HRI}{HRI} amigable, usará comandos de voz para poder comunicarse con él para guiar a las personas en espacios interiores. A diferencia de las soluciones existentes, que utilizan materiales costosos y sensores avanzados, este prototipo utilizará una CPU de baja capacidad de cómputo, como la Raspberry Pi, y técnicas avanzadas de localización interna  junto con algoritmos de navegación. Asimismo, se busca que el sistema creado sea portable para la mayoría de entornos en interiores de la manera más asequible posible sin necesidad de tener una complejidad mayor en otros entornos a la hora de programarlo y que sea capaz de poder orientarse y localizarse en el mapa mediante diferentes sensores y actuadores hasta llevar a la persona a un punto en concreto. Esto proporciona una opción más económica, práctica y versátil para la navegación en interiores.\\ 

Para cumplir con el objetivo general establecido, será necesario establecer los siguientes objetivos específicos:

\begin{enumerate}
 \item Explorar diferentes opciones de diseño para determinar la forma final del robot.
 \item Realizar una investigación sobre los distintos componentes tanto hardware como software que hay disponibles en el mercado que sean 
de bajo coste y que satisfagan las tareas de localización y movimiento del robot.
 \item Desarrollar el software necesario para poder gestionar el control del prototipo desde el ordenador sin necesidad de cables intermedios.
 \item Uso de \hyperlink{CAD}{CAD} (Computer-Aided Design) para el diseño de piezas 3D mediante el uso de software libre, como FreeCAD.
 \item Hacer uso de una impresora 3D para poder materializar las piezas necesarias. 
 \item Poder combinar todos los datos de navegación y localización sin que intervengan unos con otros mediante la librería threading que permite el control y la ejecución de diferentes hilos ejecutados en paralelo.
 \item Realizar la calibración necesaria de los sensores para asegurar la precisión de las lecturas y que sea fiable.
 \item Entrenar una red neuronal con diferentes audios por voz para enseñar a la red a clasificar e interpretar las órdenes dadas por el usuario para
 que te guíe a un sitio específico dependiendo de la orden dada por voz.
\end{enumerate}\

\section{Requisitos}
\label{sec:requisitos}

Con el objetivo de solucionar los problemas descritos, se han establecido los siguientes requisitos:

\begin{itemize}
 \item \textit{} El sistema propuesto deberá de ser capaz de poder ejecutarse en tiempo real en la plataforma Raspberry Pi 4B.
 \item \textit{} Python será el lenguaje de programación usado porque es fácil de usar, a parte de contar con una amplia gama de bibliotecas 
 y librerías útiles para este proyecto y tener soporte completo en el sistema operativo de la Raspberry Pi 4B.
 \item \textit{} El diseño y la fabricación de este prototipo no debe suponer un coste mayor a 145 \euro.
 \item \textit{} Las piezas que se usen para el diseño del robot deben ser imprimibles en cualquier impresora 3D actual.
 \item \textit{} Debe ser capaz de desplazarse sin problemas por la mayoría de suelos que hay en entornos interiores.
 \item \textit{} Es necesario que esté fabricado con el menor número de piezas posibles en 3D debido al alto tiempo que tardan en imprimirse algunas
 con el objetivo de que el usuario lo pueda montar en poco tiempo.
 \item \textit{} Contar con varios \hyperlink{APs}{APs} para que el robot se pueda localizar, por lo que mínimo con 3 valdría aunque depende de las interferencias que haya en los distintos entornos puede que se necesiten más.
 \item \textit{} Los motores y la batería deben de pesar lo menos posible, ya que a parte irán incorporadas la Power Bank y la Raspberry encima y a su vez deben proporcionar la potencia necesaria para mover todo el hardware sin problemas.
 \item \textit{} La batería debe ser recargable para que pueda usarse el robot todas las veces que se quiera y que dure lo máximo posible.
 
\end{itemize}\

\section{Metodología}
\label{sec:metodologia}

Con el fin de alcanzar los objetivos propuestos, se han utilizado distintas herramientas para poder desarrollar el proyecto correctamente y
hacer un control y seguimiento del mismo.\\

A través de la aplicación Microsoft Teams se han organizado tutorías semanales con el tutor del trabajo para hacer un seguimiento del proyecto. En estas reuniones se comentaban los problemas que iban surgiendo a lo largo de la semana y las posibles soluciones que se podían tomar para avanzar correctamente, además de la evaluación y el control de los objetivos que se habían marcado la semana anterior y establecer los nuevos objetivos y planteamientos de cara a la siguiente semana. También se ha utilizado el correo electrónico para comentar con el tutor las dudas y problemas que iban surgiendo a lo largo de la semana.\\ 

Para mantener el código y exponer los avances de este proyecto, se ha usado un repositorio de GitHub\footnote{\url{https://github.com/RoboticsURJC/tfg-vdelatorre}}, en el cual se ha ido subiendo todo el código necesario y los diferentes recursos empleados, así como imágenes, piezas, audios, artículos, etc. Al mismo tiempo, se ha diseñado una Wiki\footnote{\url{https://github.com/RoboticsURJC/tfg-vdelatorre/wiki}} en el mismo repositorio que incluye todo el proceso que se ha ido siguiendo paso a paso, junto con los diferentes problemas que han ido surgiendo y las soluciones empleadas, e imágenes y vídeos para demostrar todos los experimentos realizados y el comportamiento final del prototipo.

\section{Plan de trabajo}
\label{sec:plantrabajo}

El desarrollo completo de este proyecto se ha dividido en las siguientes etapas:

\begin{enumerate}
 \item \textit{Investigación del hardware utilizado.} El periodo de septiembre a octubre de 2023, se dedicó al aprendizaje del funcionamiento de los diferentes sensores, para poder trabajar con la Raspberry Pi a través de comandos por voz y una red neuronal entrenada para ello.

 \item \textit{Investigación del estado del arte.} En el periodo de octubre a noviembre de 2023, se hizo una investigación en diferentes plataformas, como Google Scholar, sobre artículos relacionados con el funcionamiento de la idea descrita y la compatibilidad y si era viable o no el proyecto.
 
  \item \textit{Ampliación del dataset.} En el periodo de noviembre a enero se estuvo ampliando el dataset de audios con diferentes voces y comandos para ver si era viable a largo plazo y si era escalable o no, para comprobar si era compatible con diferentes tipos de voces.
  
  \item \textit{Pruebas con motores.} En el periodo de diciembre hasta abril, se estuvo probando y analizando los motores más potentes, de menor coste y de menor peso de los que se disponía, y al mismo tiempo se estuvieron diseñando las piezas para anclarlas al robot y pensando en la estructura final para poder combinar todos los componentes. Estas piezas, una vez fueron diseñadas por ordenador en FreeCAD\footnote{\url{https://www.freecad.org/index.php?lang=es_ES}}, fueron impresas en 3D haciendo uso de una impresora de filamento de tipo \hyperlink{FDM}{FDM} (Fused Deposition Modeling) y probadas una a una para ver si eran compatibles con los motores y si disponían de la sujeción necesaria para que el robot pudiera desplazarse correctamente.
  
 \item \textit{Desarrollo de software.} Una vez montado el robot, en el periodo de abril hasta junio, se trasladó toda la red neuronal y el modelo del software probado ya con éxito en un sistema operativo Ubuntu a una Raspberry Pi probando las diferentes versiones, paquetes y librerías para que todo funcionase correctamente y se realizó una investigación sobre qué modelo de Raspberry Pi usar para soportar todo el cómputo necesario.
 
  \item \textit{Conexión VPN Raspberry Pi.} Para poder controlar el robot de manera independiente, en el periodo de junio hasta julio, se probó y se configuró el programa VNC Server en la Raspberry para no necesitar cables de conexión y que el robot se pudiera mover libremente mientras es programado desde el ordenador.
  
 \item \textit{Navegación.} Para poder controlar el robot de manera independiente, en el periodo de julio hasta diciembre, una vez diseñado el robot y probado con ambos motores, se hizo una investigación acerca de la navegación y los posibles algoritmos necesarios para trazar la ruta óptima de un punto a otro. Por otra parte, se usó la herramienta de software libre \hyperlink{GIMP}{GIMP} para diseñar el mapa del robot en el que va a navegar y también se exploraron las diferentes técnicas de navegación y localización.
 
   \item \textit{Pruebas del software desarrollado y escritura de la memoria.} En el periodo de enero hasta marzo de 2025, se realizaron todas las pruebas y cambios necesarios para que el robot cumpliera el objetivo y al mismo tiempo se fue elaborando el presente documento.
\end{enumerate}\

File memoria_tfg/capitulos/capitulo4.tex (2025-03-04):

\chapter{Plataforma de desarrollo}
\label{cap:capitulo4}

\begin{flushright}
\begin{minipage}[]{10cm}
\emph{Cuando quieres algo, todo el universo conspira para que realices tu deseo}\\
\end{minipage}\\

Paulo Coelho, \textit{El Alquimista}\\
\end{flushright}

\vspace{1cm}

En este capítulo se explicará con detalle todas las herramientas tanto a nivel hardware como software que han sido utilizadas para poder desarrollar el proyecto.

\section{Hardware}
\label{sec:hardware}

A continuación describen todos los componentes físicos que han sido utilizados en este trabajo, los cuales han sido adquiridos en su mayor parte por el precio y la funcionalidad que tienen.\\ 

\subsection{Micrófono micro USB}
\label{subsec:micro}

Utilizado para la grabación de audio, compatible con puertos USB (Figura \ref{fig:microfono-usb}) y con un tamaño y peso reducidos, lo cual lo hace ideal para incorporarlo en la Raspberry. 

Se llegó a la conclusión de que era mejor usar este tipo de micrófono, ya que no necesita cables, por lo que facilita al usuario comunicarse con el dispositivo, siendo más cómodo para él. Además de ser de bajo coste (10 \euro), es fácil de adquirir en páginas web como Amazon. Este tipo de micrófono tiene 2 metros de distancia efectiva y filtra el ruido de fondo no deseado, haciendo que el sonido sea más claro y limpio.

\begin{figure}[H] % Usa [H] para forzar la posición
  \begin{center}
    
  \end{center}
  \caption{Micrófono micro USB.}
  \label{fig:microfono-usb}
\end{figure}

\subsection{Controlador driver L298N}
\label{subsec:l298n}

Un controlador de motor o driver (Figura \ref{fig:l298n}) sirve para controlar motores de corriente continua (DC) o motores paso a paso el cual, permite sobre todo controlar tanto la velocidad como la dirección de estos motores. Este módulo hardware tiene la capacidad de transformar las señales lógicas las cuales les envía el procesador a una serie de pulsos de potencia que alimentarán ambas bobinas de cada motor reductor para hacer girar cada uno de ellos en un orden concreto. A parte, dispone de protecciones para que no se dañe en el caso de que se haga un mal uso del mismo, y siendo su precio original de solo 3 \euro.\\ 

El control del mismo es simple, primero habría que conectar el positivo de la fuente de alimentación externa de 6 V a los 12 V de la placa(Vin), y teniendo el jumper de selección de 5 V activo, ya que el módulo permite una alimentación de entre 6 - 12V y si el jumper se encuentra inactivo, se permite una alimentación de 12 - 35V pero no sería necesario en este caso ya que el motor solo necesita 6V. \\

Se recomienda no conectar nunca una tensión de entrada al pin de más de 5V cuando el jumper de 5V se encuentre activado, ya que provocaría un cortocircuito y podría dañar permanentemente el módulo. Luego, el negativo de la fuente externa tiene que ir al GND de la placa y desde este mismo, saldrá otro cable que irá al GND de la Raspberry.\\

Una vez realizada correctamente la conexión de la alimentación, es importante conectar adecuadamente los pines de control y los motores. Los pines de salida de la placa deben ir conectados a los pines de las bobinas de cada motor y los pines de entrada IN1 - IN4 irán conectados a los diferentes pines \hyperlink{GPIO}{GPIO} (General Purpose Input/Output) de la Raspberry. Si no se desactivan los jumpers de activación (ENA y ENB), ambos motores girarán a su máxima velocidad, por lo que habrá que desactivarlos para poder configurar la velocidad a la que se quiere que vaya cada motor.

\begin{figure}[H]
  \centering
   % Escala la imagen al 150% de su tamaño original
  \caption{Controlador driver L298N.}
  \label{fig:l298n}
\end{figure}

\begin{table}[H]
\begin{center}
\begin{tabular}{|c|c|}
\hline
\textbf{Parámetros} & \textbf{Valores} \\
\hline
Nombre del controlador & L298N \\
Voltaje de alimentación & 6 - 12 V(jumper) \\
Interfaz de comunicación & Pines digitales, CFG y \hyperlink{PWM}{PWM} \\
Corriente máxima de fase(RMS) & 2 x 2 A \\
Pérdida de conducción & 0.9 - 1.5~$\Omega$ \\
Voltaje lógico & 5 V \\
Dimensiones & 5 x 5 x 3 cm \\
Peso & 27 g \\
\hline
\end{tabular}
\caption{Especificaciones técnicas del L298N}
\label{cuadro:ejemplo}
\end{center}
\end{table}

La elección de este controlador se realizó teniendo en cuenta sus características, como la capacidad de manejar dos motores reductores de corriente continua y su compatibilidad con la Raspberry Pi. Una vez elegido el controlador, es importante seleccionar los motores adecuados para el desplazamiento del robot, asegurando que sean compatibles con los requisitos de corriente y voltaje del módulo.

\subsection{Motores}
\label{subsec:motores}

Un motor reductor es un tipo de motor eléctrico de corriente continua que tiene incorporado un mecanismo de reducción, como un engranaje, y que sirve para aumentar el torque de salida, es decir, una mayor fuerza en el eje del motor, lo cual es una opción idónea para esta aplicación ya que se necesita mover mucho peso contando con las piezas del robot, la Powerbank, la Raspberry y la batería, disminuyendo la velocidad de rotación y teniendo a su vez un control preciso del motor. La velocidad en este caso no es menos importante que la fuerza del motor ya que el objetivo final es que pueda desplazarse con todo el peso incorporado para llegar al destino aunque será necesaria controlarla igualmente. \\

En concreto, se han usado dos motores reductores como los que se muestran en la Figura \ref{fig:Motor}, junto con dos ruedas de anclaje que encajan perfectamente con los ejes de cada motor, y están a la venta en Amazon por un precio de 11 \euro. 

\begin{figure}[H]
  \centering
   % Escala la imagen al 150% de su tamaño original
  \caption{Motor reductor con rueda de anclaje.}
  \label{fig:Motor}
\end{figure}

\begin{table}[H]
\begin{center}
\begin{tabular}{|c|c|}
\hline
\textbf{Parámetros} & \textbf{Valores} \\
\hline

Nombre del motor & Motor reductor \\
Peso & 20 g \\  
Diámetro del eje & 3 mm \\   
Dimensiones & 70 x 22 x 18mm \\   
Torque de sujeción & 0.0687 Nm Aprox \\
Corriente máxima de fase & 850 mA \\  
Tipo de motor & Corriente continua \\   
Voltaje & 3 - 6 V \\  
Reducción & 48:1 \\ 
Velocidad sin carga & 230 rpm \\ 

\hline
\end{tabular}
\caption{Especificaciones técnicas de los motores}
\label{cuadro:ejemplo}
\end{center}
\end{table}

\subsection{Fuentes de alimentación}
\label{subsec:fuentes_alimentacion}

Para poder alimentar el controlador L298N, se va a necesitar una batería de 6 V y 6 A y que sea recargable como la que se muestra en la figura \ref{fig:bateria}, ya que se será necesaria su recarga para hacer múltiples pruebas con el robot. Esta batería consta de 5 pilas AA y un cable de carga, con un peso de 129 gramos, lo cual es perfecta para que pueda proporcionar la potencia necesaria para los motores y que a diferencia de las baterías de ácido son más ligeras, ya que éstas, normalmente son más pesadas debido a que están hechas de plomo y ácido.\\

Este tipo de fuentes se pueden encontrar en páginas como Amazon a un precio de 18 \euro, pero se podían haber usado otras que proporcionasen una alimentación en el rango de 6 - 12 V, siempre y cuando se tenga el jumper del controlador inactivo, porque si estuviese activo habría que proporcionar una alimentación entre 12 - 35 V como se mencionó anteriormente, pero como los motores necesitan 6 V solamente, pues valdría con las que se han usado. \\

Por otra parte hay que alimentar a la Raspberry, ya que el robot se debe poder mover de manera independiente y sin cables de por medio, por lo que se utilizará una Powerbank como la de la Figura \ref{fig:Powerbank}, la cual es idónea debido a su peso ligero de 200 gramos y la tensión y amperaje que proporciona de 5 V y 3 A respectivamente, ya que es justo lo que necesita la Raspberry Pi 4 que se va a utilizar para que funcione correctamente y tenga un rendimiento estable.

\begin{figure}[H]
  \begin{minipage}{0.48\textwidth}
    \centering
    
    \caption{Batería recargable con cable de carga.}
    \label{fig:bateria}
  \end{minipage}
  \hfill
  \begin{minipage}{0.48\textwidth}
    \centering
    
    \caption{Powerbank.} 
    \label{fig:Powerbank}
  \end{minipage}
\end{figure}

\subsection{Rueda loca}
\label{subsec:rueda_loca}

Para que el robot pueda desplazarse en cualquier dirección sin ningún problema se utilizará una rueda loca como la de la Figura \ref{fig:Rueda_loca} imitando el comportamiento de una pelota rodante, la cual irá anclada en la parte trasera del robot con 2 tornillos y 2 tuercas proporcionando al robot un movimiento suave y de baja fricción, de alto rendimiento y larga vida.

\begin{figure}[H]
  \centering
   % Escala la imagen al 150% de su tamaño original
  \caption{Rueda loca para robot.}
  \label{fig:Rueda_loca}
\end{figure}

\subsection{Base principal}
\label{subsec:base_principal}

Primero, habría que pensar en la forma que tiene que tener la base para poder soportar tanto los motores, como la batería, la Raspberry y la Powerbank. Para ello, se diseñará una estructura muy simple en la cual, habrá diferentes cavidades las cuales nos servirán para poder insertar de la manera más fácil posible todo lo que se necesita, como lo mencionado anteriormente más el controlador, sensores, cables y otros huecos para añadir si se requiere en un futuro otro tipo de sensores y actuadores. \\

Finalmente, para el diseño de esta base, hay que hacer uso de FreeCAD \ref{subsec:freecad} para poder imprimir esta pieza y cumplir con el objetivo establecido inicialmente de poder soportar todo el peso posible, y que sea escalable a nivel de que se pueda añadir cualquier cosa para cumplir con objetivos futuros y de esta manera también, al ser completamente Open Source, cualquier persona podrá modificarlo a su manera y utilizarlo de manera gratuita, por lo que quedaría de la siguiente manera como se puede apreciar en la Figura \ref{fig:Base_principal}:

\begin{figure}[H]
  \centering
   % Escala la imagen al 150% de su tamaño original
  \caption{Base principal.}
  \label{fig:Base_principal}
\end{figure}

Como se puede apreciar en la imagen, la cavidad circular sirve por si en algún futuro se desea añadir algún sensor más. Las dos cavidades rectangulares menores sirven para poder anclar las ruedas a los motores que irán éstos a su vez añadidos a través del hueco rectangular superior. Por otra parte, las dos cavidades rectangulares mayores, junto con el hueco de la parte trasera, sirven para poder introducir la batería como se verá más adelante de una manera asequible y sencilla. La Raspberry y la Powerbank irán encima de la parte trasera y el controlador y los cables como no hace falta que estén sujetos a nada debido a su menor peso, irán en el hueco frontal superior encima de los motores.

\subsection{Núcleo computacional}
\label{subsec:plataforma_hardware}

Para poder cumplir con el objetivo establecido de diseñar y controlar un robot guía por voz, con las características que ya se han definido en el capítulo anterior y que sea también de bajo coste, en este proyecto la infraestructura hardware se ha centrado en los sistemas embebidos que hay disponibles en el mercado. En primer lugar, una parte del software, como la de entrenar la red neuronal, se probó con éxito en un sistema operativo Ubuntu 20.04 y el siguiente paso era migrarlo a la Raspberry Pi. En segundo lugar, se intentó probar que funcionara en una Raspberry Pi 3 Model B+ pero sin éxito, ya que aunque se consiguieron instalar los mismos paquetes con las mismas versiones sin ningún problema, a la hora de instalar en concreto una de las librerías necesarias para transformar y manipular los archivos de audio como la de librosa, se experimentaron problemas de bloqueos y de rendimiento durante días sin ningún cambio apreciable, por lo que seguramente sea por limitaciones de recursos de hardware de este modelo.\\

La Raspberry Pi 3 Model B+ tiene especificaciones decentes para muchas tareas, pero ciertas aplicaciones y bibliotecas pueden ser exigentes en términos de procesamiento y memoria, lo que puede conllevar a problemas de rendimiento. La biblioteca librosa es conocida por ser computacionalmente intensiva, especialmente al trabajar con archivos de audio grandes o al realizar operaciones complejas de procesamiento de señales de audio, por lo que se esta opción queda descartada y se llegará a probar en una Raspberry Pi 4 Model B.\\

En general, la Raspberry Pi 4 ofrece un salto significativo en términos de rendimiento y capacidades en comparación con la Raspberry Pi 3 Model B+ (Figura \ref{fig:Raspberry}), ya que tiene un procesador más potente y mucha más RAM (4 GB), lo que la hace más capaz de manejar tareas intensivas y ejecutar aplicaciones más exigentes. Para usarla correctamente, habrá que añadir disipadores de calor y un ventilador, ya que genera más calor que la Raspberry Pi 3 Model B+.

\begin{figure}[H]
  \centering
   % Escala la imagen al 150% de su tamaño original
  \caption{Raspberry Pi 4B vs Raspberry Pi 3B+.}
  \label{fig:Raspberry}
\end{figure}

Esta placa tiene pines \hyperlink{GPIO}{GPIO} los cuales permiten que se conecten tanto sensores como actuadores mediante diferentes tipos, como los que se muestran en la Figura \ref{fig:Pines}. Hay diferentes tipos de pines:

\begin{itemize}
 \item \textit{GND.} Es usado para poder cerrar el circuito eléctrico y que la corriente pueda fluir adecuadamente entre los dispositivos conectados y no haya ningún daño. Son los pines 6, 9, 14, 20, 25, 30, 34 y 39.
 \item \textit{Pin de 5V.} En los pines 2 y 4 se proporciona una alimentación de 5V.
 \item \textit{Pin de 3V.} En los pines 1 y 17 se proporciona una alimentación de 3V.
 \item \textit{Modulación por ancho de pulso (\hyperlink{PWM}{PWM}).} Se corresponden con los pines 12, 32, 33 y 35 y permiten modificar el ciclo de trabajo con una señal periódica establecida.
 \item \textit{Conexión \hyperlink{UART}{UART} (Universal Asynchronous Receiver-Transmitter).} Se corresponden con los pines 8 y 10.
 \item \textit{Conexión \hyperlink{SPI}{SPI} (Serial Peripheral Interface).} Se corresponden con los pines 19, 21, 23, 24 y 26.
 \item \textit{Conexión \hyperlink{I2C}{I2C} (Inter-Integrated Circuit).} Se corresponden con los pines 3 (SDA), 5 (SCL), 27 (SDA) y 28 (SCL).	
 \item \textit{} Los demás pines son usados para garantizar la conexión de entrada o salida con el dispositivo conectado. 
\end{itemize}\

\begin{figure}[H]
  \centering
   % Escala la imagen al 150% de su tamaño original
  \caption{Diferentes tipos de pines GPIO en Raspberry Pi 4B.}
  \label{fig:Pines}
\end{figure}

\subsection{Magnetómetro}
\label{subsec:magnetómetro}

Para obtener la orientación absoluta del robot se puede usar un sensor como el MPU9250 (Figura \ref{fig:mpu9250}). Este dispositivo compacto y versátil combina el acelerómetro de 3 ejes, el giroscopio de 3 ejes y el magnetómetro de 3 ejes en un solo paquete, por lo puede medir la aceleración lineal, la velocidad angular y la intensidad del campo magnético terrestre en los 3 ejes.\\ \\ Tiene integrado un \hyperlink{DMP}{DMP} (Digital Motion Processor) capaz de realizar complejos algoritmos de captura de movimiento de los 9 ejes. Este sensor se comunica con microcontroladores a través de la interfaz I2C y posee una librería muy extensa para su uso inmediato e incorpora un regulador de voltaje a 3.3V en la placa y resistencias pull-up para su uso directo por I2C. Para una captura precisa de movimiento rápido y lento, tiene un rango de escala programable de 250/500/1000/2000 º/seg para el giroscopio, 2g/4g/8g/16g para el acelerómetro y ±4800µT para el magnetómetro.\\ \\
Su magnetómetro incorporado se puede utilizar para estimar el ángulo de orientación absoluta como el de una brújula. Este ángulo conocido como acimut, se refiere a la dirección en la que apunta un objeto o una persona, en relación normalmente con el norte.\\ \\ Una lectura de 0º indicaría una dirección hacia el norte verdadero, 90º, 180º y 270º indicarían este, sur y oeste, respectivamente. Se puede determinar este ángulo utilizando las lecturas del magnetómetro con otras técnicas de calibración para estimar con alta precisión en qué dirección va, resultando así muy útil para que el robot pueda orientarse en interiores.

\begin{figure}[H]
  \centering
   % Escala la imagen al 150% de su tamaño original
  \caption{Sensor MPU9250.}
  \label{fig:mpu9250}
\end{figure}

\begin{table}[H]
\begin{center}
\begin{tabular}{|c|c|}
\hline
\textbf{Parámetros} & \textbf{Valores} \\
\hline

Nombre del sensor & MPU9250 \\
Voltaje de operación & 3.3 - 5 V \\  
Grados de libertad(\hyperlink{DoF}{DoF}) & 9 \\   
Rango de acelerómetro & ±2g, ±4g, ±8g, ±16g \\   
Rango Giroscopio & ±250º/Seg, ±500º/Seg, ±1000º/Seg, ±2000º/Seg \\
Rango Magnetómetro & ±4800 $ \mu $T \\  
Interfaz & I2C y SPI \\   
Conversor AD & 16 Bits (salida digital) \\   
Dimensiones & 25 x 16 x 3mm \\
Consumo de energía(modo activo) & 3.2 mA \\
Temperatura de funcionamiento & -40ºC a +85ºC \\ 

\hline
\end{tabular}
\caption{Especificaciones técnicas del sensor MPU9250}
\label{cuadro:ejemplo}
\end{center}
\end{table}

\subsection{Sensor de ultrasonido}
\label{subsec:hscr04}

Para tratar la navegación local, se ha usado un sensor de ultrasonido como el HC-SR04 (Figura \ref{fig:hcsr04}). Este sensor es necesario para poder evitar los obstáculos que van apareciendo en interiores a medida que el robot se desplaza al objetivo final, como personas, paredes, muebles, mascotas, etc. Este sensor mide las distancias usando ondas ultrasónicas que viajan en el aire hasta chocar contra un objeto y una vez rebotan, son detectadas por este sensor y se mide el tiempo que tarda la onda en regresar. Con estos datos se puede calcular la distancia a un obstáculo con esta fórmula \ref{ec:ec8}:

\begin{myequation}[h]
\begin{equation}
Distancia = \frac{Tiempo * \textit{Velocidad del sonido}}{2}
\nonumber
\label{ec:ec8}
\end{equation}
\caption[Ecuación de distancia basada en ultrasonidos]{Ecuación de distancia basada en ultrasonidos}
\end{myequation} 

\begin{figure}[H]
  \centering
   % Escala la imagen al 150% de su tamaño original
  \caption{Sensor de ultrasonido HC-SR04.}
  \label{fig:hcsr04}
\end{figure}

\section{Software}
\label{sec:software}

Al hacer uso finalmente de una Raspberry Pi 4B, se usó el sistema operativo oficial Raspberry Pi OS (Figura \ref{fig:raspbian}) con la versión de 64 bits, y, como está basado en Debian, se dispondrá de las cualidades de un sistema Linux. Se ha decidido usar este sistema operativo debido a su optimización para que pueda funcionar en procesadores ARM (el que ya tiene la Raspberry) ofreciendo así el mejor rendimiento posible para este placa.

Posteriormente, se definirán todos las librerías externas y programas que han sido necesarios para poder desarrollar este proyecto correctamente.

\begin{figure}[H]
  \centering
   % Escala la imagen al 150% de su tamaño original
  \caption{Raspberry Pi OS.}
  \label{fig:raspbian}
\end{figure}

\subsection{Python}
\label{subsec:python}

Python es un lenguaje de programación interpretado de alto nivel y orientado a objetos, es decir, al ser de alto nivel su nivel de abstracción es más cercano al lenguaje humano que al de una máquina y es de fácil uso en comparación con los lenguajes de bajo nivel. Es interpretado en el sentido que es un intérprete el que ejecuta línea por línea en vez de ser compilado a código máquina previamente como en C o C++. Es uno de los lenguajes de programación más usados en el mundo debido a su amplia librería estándar, garantizando así multitud de funciones y módulos para realizar diferentes tareas y a su vez, está soportado de manera nativa por el sistema operativo utilizado Raspbian.\\ \\ También cuenta con una gran variedad de librerías de terceros como Numpy para cálculos numéricos, Pandas para el análisis de datos, librosa para la manipulación de datos de audio lo cual será de gran ayuda a la hora de entrenar la red neuronal con los comandos y seaborn para la visualización de datos estadísticos, entre otros. En este proyecto, Python se usará para leer y procesar los datos de los sensores de manera concurrente proporcionando órdenes a los actuadores para alcanzar un objetivo en concreto.

\subsection{FreeCAD}
\label{subsec:freecad}

FreeCAD es una herramienta de software libre y gratuito el cual es usado para modelar y diseñar piezas en 3D para posteriormente ser impresas. Su modelo se basa en usar una serie de parámetros para poder construir modelos en 3D para que se puedan modificar de una manera sencilla. Entre las ventajas que tiene este programa de diseño, está la de tener un banco de trabajo, el cual es un conjunto de herramientas especializadas para poder realizar una tarea específica dentro del software como el modelado paramétrico. 

\begin{figure}[H]
  \centering
   % Escala la imagen al 150% de su tamaño original
  \caption{Logo de FreeCAD.}
  \label{fig:freecad}
\end{figure}

La comunidad también es capaz por otra parte de agregar nuevas herramientas y funciones al software, por lo que esta herramienta va mejorando continuamente y no es muy difícil de entender y aprender todos los conceptos necesarios para poder usarla correctamente debido a toda la documentación que hay junto con los tutoriales correspondientes.

\subsection{Scikit-learn}
\label{subsec:sklearn}

Scikit-learn es probablemente la biblioteca más útil para el aprendizaje automático de software libre en Python. La biblioteca sklearn contiene muchas herramientas eficientes para el aprendizaje automático y el modelado estadístico, incluidas la clasificación, la regresión, la agrupación y la reducción de la dimensionalidad.\\ Para este proyecto, se usarán partes específicas de esta biblioteca para así evitar cargar todo el módulo entero y hacer el código más claro ya que se importa solamente lo que se necesita. \\

En concreto, se usarán las partes para escalar o normalizar las características antes de entrenar el modelo, para implementar diferentes algoritmos de aprendizaje automático y funciones para dividir el conjunto de datos en diferentes subconjuntos de datos de entrenamiento, que son los que se han utilizado para entrenar el modelo de entrenamiento y prueba y verificar su capacidad de una manera más eficiente.\\

También proporcionará varias métricas que se pueden utilizar para poder evaluar el rendimiento de los diferentes modelos o algoritmos de clasificación, resultando así muy útil para elegir el modelo final para el entrenamiento de la red neuronal.

\begin{figure}[H]
  \centering
   % Escala la imagen al 150% de su tamaño original
  \caption{Logo de la biblioteca Scikit-learn.}
  \label{fig:sklearn}
\end{figure}

\subsection{Librosa}
\label{subsec:librosa}

Librosa es un paquete de Python para el análisis y procesamiento de música y audios. De esta manera, proporciona las herramientas necesarias para poder extraer las características y la manipulación de un audio y la respectiva visualización de los datos del sonido del mismo. En concreto servirá para calcular el espectrograma de un audio que es una representación visual en la que se muestra la intensidad de señal del audio y la frecuencia a través de la \hyperlink{STFT}{STFT} (Short-Time Fourier Transform), permitiendo analizar así cómo va cambiando la frecuencia con el tiempo.\\

También permite calcular el cronograma de un audio que es una representación de la intensidad de todas las notas musicales que están presentes en un audio y a su vez, calcular los coeficientes \hyperlink{MFCC}{MFCC} (Mel-Frecuency Cepstral Coefficients) de un audio que son las características más importantes de un audio respecto con la percepción sonora del humano sobre ese audio.\\

A partir de estas características extraídas, es posible construir representaciones que faciliten la diferenciación entre distintos tipos de audios. Este análisis es imprescindible para dotar a los modelos de clasificación de información relevante y mejorar su capacidad de diferenciar entre múltiples categorías de audio.\\

En resumen, con todas estas características de cada audio por voz, se podrán usar los modelos de clasificación para predecir la clase a la que pertenece cada audio. 

\begin{figure}[H]
  \centering
   % Escala la imagen al 150% de su tamaño original
  \caption{Logo del paquete Librosa.}
  \label{fig:librosa}
\end{figure}

\subsection{Smbus2 y mpu9250\_jmdev}
\label{subsec:smbus2mpu9250jmdev}

Smbus2 es una biblioteca la cual es una versión mejorada de la biblioteca smbus y es utilizada en general para la comunicación con los dispositivos I2C como en este caso que es el MPU9250 para calcular la orientación del robot. Tiene un enfoque distinto al de la biblioteca \textit{mpu9250\_jmdev} en cuanto a la implementación para poder interactuar con el MPU9250 a través de I2C, ya que la primera se usa para poder acceder a los registros del sensor de una manera más manual y escribir todas las funciones necesarias para la lectura de los valores del mismo teniendo así un control sobre el hardware pero se requiere tener un conocimiento pleno de este protocolo y de cómo funciona este sensor.\\

En cambio, la biblioteca \textit{mpu9250\_jmdev} abstrae la comunicación con los registros de esta comunicación, proporcionando así una clase la cual ya tiene implementada todos los métodos de alto nivel necesarios para poder interactuar con el dispositivo y obtener los datos del giroscopio, acelerómetro, y magnetómetro, simplificando así el proceso de escribir y leer en los registros del MPU9250 como se hacía con la anterior biblioteca y de esta manera no se profundiza demasiado en el protocolo y teniendo así un enfoque mucho más directo y simple.

\subsection{Jupyter Notebook}
\label{subsec:Jupyter}

Jupyter Notebook es un entorno web interactivo que permite a los usuarios crear y compartir documentos que contienen código en tiempo real, visualizaciones y texto narrativo. De esta manera, todo el entorno que tiene el usuario se podrá visualizar en esta herramienta mediante una interfaz amigable y permitiendo a su vez ejecutar celdas de código de manera individual como se puede apreciar en la Figura \ref{fig:jup1}, lo que facilita a su vez el análisis paso a paso y ver los resultados de cada celda al momento.\\

\begin{figure}[H]
  \centering
   % Escala la imagen al 150% de su tamaño original
  \caption{Interfaz Jupyter Notebook.}
  \label{fig:jup1}
\end{figure}

Esta herramienta también sirve para manejar bases de datos de prueba y entrenamiento con modelos de aprendizaje automático, ya que se pueden cargar datos y procesarlos de manera interactiva, lo cual será muy útil para hacer las correspondientes pruebas sobre cuántos \hyperlink{APs}{APs} son necesarios para que el robot pueda localizarse como se verá más adelante, ya que para esto se necesitará recoger una gran cantidad de datos de cada \hyperlink{APs}{APs} para que cada modelo sea capaz de procesar todos los datos.

\subsection{GIMP}
\label{subsec:gimp}

\hyperlink{GIMP}{GIMP} es un programa de edición de imágenes de software libre y gratuito en el cual se pueden editar imágenes digitales en forma de mapa de bits, tanto fotografías como dibujos. Para este proyecto, se usará para diseñar el mapa del robot, es decir, dibujar en una imagen píxel a píxel los obstáculos por donde no podrá desplazarse el robot. Para ello se puede hacer uso de las diferentes herramientas como el pincel, lápiz o el borrador y después una vez dibujado el mapa se podrá exportar como una imagen en un formato determinado y ejecutar un programa que hace uso de la Clase Image del módulo PIL que es una biblioteca para trabajar con imágenes en Python y de esta manera poder abrir la imagen, obtener sus dimensiones e iterar sobre cada píxel para escribir la representación binaria, guardarla en formato txt y así esta matriz será la que se le pasará al algoritmo A* para encontrar el camino más óptimo.

\subsection{Bibliotecas auxiliares empleadas}
\label{subsec:bibliotecas}

A parte de los módulos y bibliotecas mencionadas anteriormente, también se usaron otras herramientas de propósito general. La biblioteca \texttt{threading}, la cual se usó para implementar programación concurrente y poder manejar diferentes programas a la vez, como la obtención del ángulo de orientación; mientras que \texttt{subprocess} sirvió para ejecutar comandos externos desde Python, como ejecutar el comando para conectarse a una red WiFi o para grabar un archivo de audio. Para el análisis y manipulación de los datos de audio, se usaron \texttt{pandas} y \texttt{numpy}, que son ampliamente usadas en el ámbito científico. La biblioteca \texttt{heapq} facilitó la gestión eficiente de las estructuras de datos basadas en montículos (heaps), que en este caso se usó sobre todo para manejar el algoritmo A* de una manera más óptima; y \texttt{deque} se usó para obtener las últimas lecturas del magnetómetro. Finalmente, se utilizó \texttt{matplotlib.pyplot} para generar y guardar imágenes que ilustraban los resultados obtenidos del algoritmo.\\

Se recomienda instalar todos los paquetes necesarios en un entorno virtual, que es un directorio con su propia instalación de Python y sus paquetes, ofreciendo así un control preciso sobre las dependencias de software, el aislamiento de entornos de trabajo y la capacidad de experimentar y probar configuraciones sin afectar al sistema operativo principal, por lo que sería útil instalar la biblioteca \texttt{virtualenv}.

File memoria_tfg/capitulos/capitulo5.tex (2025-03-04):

\chapter{Arquitectura software}
\label{cap:capitulo5}

\begin{flushright}
\begin{minipage}[]{10cm}
\emph{Somos lo que hacemos repetidamente, por lo que la excelencia no es un acto, sino un hábito}\\
\end{minipage}\\

Charles Duhigg, \textit{El poder de los hábitos}\\
\end{flushright}

\vspace{1cm}

En este capítulo se describe la topología del sistema utilizado, tanto a nivel software como a nivel hardware. También se describe la forma en la que los diferentes elementos software se complementan, explicando cómo funcionan juntos y detallando los aspectos más importantes de cada uno de ellos.

\section{Estructura hardware}
\label{sec:estructura_hardware}

Para este proyecto se ha usado la Raspberry Pi 4B, debido a su bajo coste y su capacidad de potencia y rapidez con respecto al modelo anterior. El sistema operativo utilizado ha sido Raspberry Pi OS en su versión de 64 bits. Para la conexión de los diferentes sensores y actuadores se han utilizado los puertos \hyperlink{GPIO}{GPIO} ya presentados en la sección \ref{subsec:plataforma_hardware}. En la Figura \ref{fig:circuito} se pueden apreciar las diferentes conexiones de los sensores y actuadores a la Raspberry. A continuación se explicarán los detalles de las conexiones de estos componentes hardware :

\begin{itemize}
 \item \textit{Magnetómetro (Figura \ref{fig:mpu9250}).} Este sensor necesita dos pines SDA y SCL, ya que funciona por conexión I2C, por lo que siguiendo el esquema de la Figura \ref{fig:circuito}, se ha conectado a los pines 3 y 5 respectivamente. También se ha conectado al pin 39 (GND) para la toma de tierra y al pin 4 para tener la alimentación de  5V. 
 \item \textit{Micrófono micro USB (Figura \ref{fig:microfono-usb}).} Este sensor se ha conectado en el puerto USB que ofrece la Raspberry de entre los 4 que hay.
 \item \textit{Controlador driver L298N (Figura \ref{fig:l298n}).} Este módulo hardware tiene conectados a la Raspberry los terminales ENA, ENB, IN1, IN2, IN3, IN4 y ENB a los pines 32, 36, 35, 38, 37 y 12 respectivamente. También tiene conectados los terminales GND y VCC a los dos pines de la batería recargable y el mismo terminal GND al pin 34 (GND). Ambos pines de cada motor deben ir conectados a los pines de salida del controlador, OUT1 Y OUT2 para un motor y OUT3 y OUT4 para el otro.
 \item \textit{Powerbank (Figura \ref{fig:Powerbank}).} Esta fuente de alimentación irá conectada al puerto USB-C para proporcionar a la Raspberry los 5V y 3A necesarios.
  \item \textit{HC-SR04 (Figura \ref{fig:hcsr04}).} Esta sensor consta de 4 pines: VCC, GND, TRIG y ECHO. Los 3 primeros irán conectados a los pines 2, 30 y 16 respectivamente. El pin ECHO devuelve 5V y esto podría dañar la Raspberry Pi, ya que sus pines \hyperlink{GPIO}{GPIO} manejan voltajes de 3.3V, por lo que habría que usar un divisor de voltaje con dos resistencias de 1000 $\Omega$ y 2000 $\Omega$ que reducen la señal de 5V a 3.3V y se conectará al pin 18 y al GND a partir de ambas resistencias.
\end{itemize}\

\begin{figure}[H]
  \centering
   % Escala la imagen al 150% de su tamaño original
  \caption{Esquema de conexiones.}
  \label{fig:circuito}
\end{figure}

\section{Desarrollo software}
\label{sec:desarrollo_software}

Después de diseñar la plataforma hardware, el siguiente paso será darle soporte software, por lo que será necesario calcular el ángulo de orientación del robot, la localización en el mapa, proporcionar un algoritmo que calcule la ruta óptima, y que funcione la red neuronal con distintos comandos por voz, entre otras cosas.

\subsection{Orientación del robot}
\label{subsec:orientacion_robot}

Para poder realizar giros más precisos y tener una trayectoria controlada del robot, es necesario calcular el ángulo de orientación de este dispositivo MPU9250, que como ya se mencionó anteriormente, cuenta con un magnetómetro de 3 ejes, por lo que, utilizando estas lecturas con otras técnicas de calibración, se podrá estimar con alta precisión en que dirección va. Para ello, habrá que actualizar la lista de paquetes, instalar el administrador de paquetes de Python \verb|python3-pip|  e instalar la biblioteca \verb|smbus2| necesaria para I2C, y también la biblioteca \verb|mpu9250-jmdev| específicamente para el MPU9250.

Por otra parte, es muy importante activar el protocolo de I2C para que se pueda comunicar con la Raspberry y le pueda transmitir los datos adquiridos. Esto se activa en: Preferences \texttt{->} Raspberry Pi Configuration \texttt{->} Interfaces \texttt{->} I2C. Si estaba desactivada, es necesario reiniciar la Raspberry. Una vez hecho esto, para ver si lo ha reconocido bien el sensor, habría que ejecutar el comando \textit{i2cdetect -y 1}, el cual dará una tabla que muestra las direcciones I2C de los dispositivos detectados, y habrá que comprobar que detectó un dispositivo. Como se puede apreciar en la Figura \ref{fig:bus}, lo detectó en la dirección 0x68.

\begin{figure}[H]
  \centering
   % Escala la imagen al 150% de su tamaño original
  \caption{ Direcciones I2C de los dispositivos detectados.}
  \label{fig:bus}
\end{figure}

El siguiente paso sería obtener las lecturas del magnetómetro. Para ello, habrá que hacer uso de la clase \ref{cod:codejemplo} proporcionada por la biblioteca \texttt{mpu9250\_jmdev}. En primer lugar, se crea una instancia de esta clase con el constructor, con una serie de parámetros que definen la configuración del sensor, que son los siguientes:

\begin{itemize}
 \item \textit{Address\_ak:} Esta es la dirección la cual especifica dónde está conectado el magnetómetro en el bus I2C cuyo valor por defecto es \texttt{AK8963\_ADDRESS}.
 \item \textit{Address\_mpu\_master:} Esta es la dirección I2C del MPU9250 cuyo valor por defecto es \texttt{MPU9050\_ADDRESS\_68}.
 \item \textit{Address\_mpu\_slave:} Esta es la dirección I2C del MPU9250 esclavo si existe, es decir, si se usa un segundo dispositivo cuyo valor por defecto es \textit{None}.
 \item \textit{Bus:} Este es el número del bus I2C que por defecto es 1.
 \item \textit{Gfs:} Este es el rango de sensibilidad del giroscopio que por defecto es \texttt{GFS\_2000 ($\pm 2000^\circ$/seg)}.
 \item \textit{Afs:} Este es el rango de sensibilidad del acelerómetro que por defecto es \texttt{AFS\_16G ($\pm 16G$)}.
 \item \textit{Mfs:} Este es el rango de sensibilidad del magnetómetro que por defecto es \texttt{AK8963\_BIT\_16 (16 bits)}.
 \item \textit{Mode:} Este es el modo de operación del magnetómetro el cual establece el modo de funcionamiento y la frecuencia de muestreo cuyo valor por defecto es \texttt{AK8963\_MODE\_C100HZ}.
\end{itemize}

Luego se configura el sensor para inicializarlo con los parámetros dados mediante el método \verb|configure (self, retry=3)|. El parámetro \textit{retry} es el número de intentos para configurar el sensor que por defecto vale 3 por si ocurre algún error en la configuración, pues se intenta de nuevo las veces que el parámetro retry diga. Dentro de este método, se llama a \verb|configureMPU6500 (gfs, afs)| para configurar el giroscopio y acelerómetro con las escalas determinadas y también se llama a \verb|configureAK8963 (mfs, afs)| para configurar el magnetómetro con el modo y la resolución especificadas y si se agotan los intentos dando error en todos se lanza una excepción.\\

A continuación se capturan los datos del magnetómetro con la función \verb|readMagnetometerMaster (self)| para obtener los 3 componentes del campo magnético medidos en cada uno de los ejes. Primero verifica si hay algún MPU9250 esclavo conectado con el método \verb|hasSlave| y si lo hay, lee los datos desde el esclavo con la función \verb|readMaster (EXT_SENS_DATA_14, 7)|, el primer parámetro se corresponde con una dirección específica de un registro en el MPU9250 y el segundo es la cantidad de bytes que se quieren leer.\\

Si no hay ningún esclavo conectado, lee los datos directamente del magnetómetro con la función \verb|readAK (AK8963_MAGNET_OUT, 7)|, siendo similar a la anterior. Finalmente, los datos leídos se convierten a unidades compatibles con el método \verb|convertMagnetometer (data)| y si ocurre algún error al leerlos devuelve un valor de error definido por la función \verb|getDataError|.\\

Para esta aplicación, solamente se hará uso de las componentes x e y, ya que el objetivo es determinar la dirección del norte magnético en el plano horizontal. La componente z no se utiliza ya que no aporta información relevante, ya que funciona igual que una brújula y ésta misma mide la dirección en el plano horizontal con el ángulo calculado en el plano XY.

\begin{code}[H]
\begin{lstlisting}[language=Python]
class MPU9250:
    def __init__(self, 
        address_ak=AK8963_ADDRESS, 
        address_mpu_master=MPU9050_ADDRESS_68, 
        address_mpu_slave=None, 
        bus=1, 
        gfs=GFS_2000, 
        afs=AFS_16G, 
        mfs=AK8963_BIT_16, 
        mode=AK8963_MODE_C100HZ
    )
       
    def configure(self, retry=3):
        try:
            self.configureMPU6500(self.gfs, self.afs)
            self.configureAK8963(self.mfs, self.mode)
        except OSError as err:
            if(retry > 1):
                self.configure(retry - 1)
            else:
                raise err
     
    def readMagnetometerMaster(self):
        try:
            data = None
            if self.hasSlave():
                data = self.readMaster(EXT_SENS_DATA_14, 7)          
            else:   
                data = self.readAK(AK8963_MAGNET_OUT, 7)
            return self.convertMagnetometer(data)
        except OSError:
            return self.getDataError()           
\end{lstlisting}
\caption[Clase MPU9250]{Clase MPU9250}
\label{cod:codejemplo}
\end{code}

Finalmente, para calcular el ángulo de orientación, habrá que hacer uso de la función \verb|math.atan2 (y,x)| para calcular el ángulo entre el vector formado por los parámetros XY y el eje positivo X, siendo x e y las lecturas magnéticas medidas por el magnetómetro. Este ángulo está en radianes por lo que habría que pasarlo a grados multiplicando por 180 y dividiendo entre \(\pi\).\\

La función \verb|math.atan2 (y,x)| puede devolver un valor negativo en ciertos casos, y lo ideal es que se mantenga en el rango de 0º y 360º mediante esta condición \ref{cod:codejemplo3}.

\begin{code}[H]
\begin{lstlisting}[language=Python]
if heading_angle_in_degrees < 0:
    heading_angle_in_degrees += 360
\end{lstlisting}
\caption[Condición para mantener el ángulo en el rango correcto]{Condición para mantener el ángulo en el rango correcto}
\label{cod:codejemplo3}
\end{code}

Es importante tener en cuenta también el concepto de declinación magnética, que es el ángulo que existe entre el norte verdadero (Polo Norte geográfico) y el norte magnético que es la dirección hacia el Polo Norte magnético que cambia con el tiempo. Una brújula normal apunta al norte magnético y no al norte verdadero. En este proyecto no se tendrá en cuenta esta desviación, que es diferente dependiendo del lugar, ya que al ser en interiores no varía casi nada este factor pero si fuese en exteriores sí que habría que tenerlo en cuenta. Para saber la declinación magnética de un lugar específico de la Tierra se puede hacer uso de esta página web\footnote{\url{https://www.magnetic-declination.com/}}.\\

Una vez obtenido el ángulo de orientación, se comprueba que las medidas no son exactas y varían mucho, por lo que es necesario calibrar el dispositivo como se muestra en la Sección \ref{sec:cal_mag}.

\subsection{Diseño del mapa}
\label{subsec:diseño_mapa}

Dentro de la navegación global, el robot parte de un mapa conocido gestionado de la siguiente forma. Primero, se hace uso de la herramienta \hyperlink{GIMP}{GIMP}, como ya se mencionó en la Sección \ref{subsec:gimp} para la edición de imágenes, en la que se tendrá un fondo en blanco y se pintarán de color negro aquellos píxeles que representen obstáculos para el robot y también los \hyperlink{APs}{APs} como se puede apreciar en la Figura \ref{fig:mapa_apes}, ya que se consideran obstáculos por donde no podrá pasar el robot\footnote{En este caso se pintaron de azul para poder distinguirse de un obstáculo normal aunque en el mapa final irán pintados en color negro}.

\begin{figure}[H]
  \centering
   % Escala la imagen al 150% de su tamaño original
  \caption{ Mapa de ejemplo en GIMP con los APs establecidos.}
  \label{fig:mapa_apes}
\end{figure}

Los píxeles de alrededor de estos obstáculos también se pintarán de color negro para tener un margen de seguridad en los cálculos de movimiento junto con los \hyperlink{APs}{APs} como se puede apreciar en la Figura \ref{fig:astar7}:

\begin{figure}[H]
  \centering
   % Escala la imagen al 150% de su tamaño original
  \caption{ Ejemplo del mapa final con los obstáculos ampliados.}
  \label{fig:astar7}
\end{figure}

Los colores de cada píxel del mapa tienen importancia y se ha diseñado así ya que el algoritmo de navegación trabaja con una matriz de 0 y 1 por la cual navegará el robot por los valores de la matriz que tienen un 1 que representa el color blanco. Una vez exportada la imagen en formato png, se hará uso de la Función \ref{cod:codejemplo4}, la cual recorre los píxeles de la imagen viendo los valores de cada uno y escribe un 0 o 1 dependiendo del color del píxel, aceptando como parámetros la imagen y un archivo vacío en formato txt en el que se escribirá la matriz.

\begin{code}[H]
\begin{lstlisting}[language=Python]
def image_to_binary_text(image_path, output_file):
    # Abrir la imagen en blanco y negro
    img = Image.open(image_path).convert('1') 

    width, height = img.size
   
    with open(output_file, 'w') as f:
        # Iterar sobre cada pixel de la imagen
        for y in range(height):
            for x in range(width):
                pixel = img.getpixel((x, y))

                bit_value = '0' if pixel == 0 else '1'

                f.write(bit_value)

            f.write('\n') 
\end{lstlisting}
\caption[Función para convertir una imagen en representación binaria ]{Función para convertir una imagen en representación binaria}
\label{cod:codejemplo4}
\end{code}

Finalmente el archivo de salida con la representación binaria de la matriz (Figura \ref{fig:bin}) es el que se le pasará al algoritmo de navegación A* para poder navegar por ella. 

\begin{figure}[H]
  \centering
   % Escala la imagen al 150% de su tamaño original
  \caption{ Ejemplo de la representación binaria del mapa.}
  \label{fig:bin}
\end{figure}

\subsection{Interfaz de usuario}
\label{subsec:interfaz_usuario}

Una de las mejores formas de interactuar con el robot es mediante comandos de voz ya que es muy natural e intuitivo para los usuarios. El primer paso sería tener un dataset de audios de prueba en español con los comandos de voz que reconocerá el robot. Estos audios deben ir en formato WAV, ya que a diferencia del formato MP3, el formato WAV es un formato de audio sin pérdida, por lo que no hay compresión con pérdida de información auditiva y cada vez que un archivo MP3 se comprime, se pierde cierta información para reducir el tamaño del archivo y podría afectar la calidad del sonido y al rendimiento de la red neuronal, y la calidad del audio en este caso es crucial. Al no haber pérdidas en el formato WAV, aumentan los bytes de cada audio por lo que para que se puedan clasificar correctamente, tras diferentes pruebas realizadas cada audio no podrá superar los 200 bytes.\\

Las clases deberían estar equilibradas para facilitar la tarea de entrenamiento; es decir, debería de haber el mismo número de audios para cada clase. Cada audio tiene asignado un número que representa la clase a la que pertenece, como por ejemplo \texttt{ej1-01-.wav}. Las diferentes clases representan los diferentes comandos que hay.\\

 El siguiente paso sería cargar cada uno de los audios y extraer las características de cada uno de ellos para calcular la transformada de Fourier del espectrograma del audio (\hyperlink{STFT}{STFT}), los coeficientes cepstrales de frecuencias mel (\hyperlink{MFCC}{MFCC}) y los espectrogramas mel, ya que son propiedades que usará el modelo para clasificar cada archivo de audio. Para calcular estas características, primero se calcula la forma de onda para diferentes audios (Figura \ref{fig:onda}), y se puede observar que hay una diferencia visible entre comandos diferentes, pero no la suficiente para clasificarlos.
 
 \begin{figure}[H]
  \centering
   % Escala la imagen al 150% de su tamaño original
  \caption{ Forma de onda de diferentes audios.}
  \label{fig:onda}
\end{figure}

Para calcularla basta con abrir el archivo y leer los datos de audio en formato \texttt{float32} que es un formato estándar para procesar señales de audio. De esta manera, se convierte la señal en un array en la que cada elemento representa la amplitud del audio guardado en \texttt{waveform}. También se calcula la frecuencia de muestreo que será necesaria para pasos posteriores.

\begin{verbatim}
with soundfile.SoundFile(file) as audio:
        waveform = audio.read(dtype="float32")
        sample_rate = audio.samplerate
\end{verbatim}

Para poder calcular la \hyperlink{STFT}{STFT} (Figura \ref{fig:stft}) se hace uso de la función \verb|feature_chromagram (waveform, sample_rate)|, la cual toma la forma de onda y la frecuencia de muestreo y calcula la \hyperlink{STFT}{STFT} del audio que descompone la señal en sus componentes de frecuencia a lo largo del tiempo y toma su valor absoluto, teniendo así una matriz en la cual las columnas representan los frames de tiempo y las filas representan las frecuencias. Luego lo convierte en un cronograma (Figura \ref{fig:cronograma}) que mide la energía de cada una de las notas musicales presentes en el frame, siendo una matriz cambiando las filas que son las notas musicales con las columnas (frames) y finalmente calcula la media de cada columna teniendo así un vector de 12 componentes en la que cada elemento representa la energía media de una nota en todo el audio.

\begin{code}[H]
\begin{lstlisting}[language=Python]
def feature_chromagram(waveform, sample_rate):
    stft_spectrogram=np.abs(librosa.stft(waveform))
    chromagram=np.mean(librosa.feature.chroma_stft(S=stft_spectrogram, sr=sample_rate).T,axis=0)
    return chromagram
\end{lstlisting}
\caption[Función para calcular la STFT de un audio]{Función para calcular la STFT de un audio}
\label{cod:codejemplo6}
\end{code}

\begin{figure}[H]
  \centering
   % Escala la imagen al 150% de su tamaño original
  \caption{ Representación de la transformada de Fourier de corta duración de un audio.}
  \label{fig:stft}
\end{figure}

\begin{figure}[H]
  \centering
   % Escala la imagen al 150% de su tamaño original
  \caption{ Representación del cronograma de un audio.}
  \label{fig:cronograma}
\end{figure}

Con la forma de onda y la frecuencia de muestreo, también se pueden calcular los coeficientes \hyperlink{MFCC}{MFCC} (Figura \ref{fig:mfcc}) que nos dan una idea del tono cambiante de una señal de audio. Con la función \verb|feature_mfcc (waveform, sample_rate)|, se calculan los \hyperlink{MFCC}{MFCC} de una señal y en este caso como indica el parámetro \texttt{n\_mfcc}, se calculan 40 coeficientes para tener más detalles del contenido espectral, ya que para esta tarea 40 coeficientes proporcionan la mejor precisión y un cálculo rápido. El atributo ``\texttt{.T}" transpone la matriz intercambiando así los coeficientes con los fotogramas de tiempo y luego se calcula la media de cada columna generando así un vector de tamaño 40.

\begin{code}[H]
\begin{lstlisting}[language=Python]
def feature_mfcc(waveform, sample_rate):
    mfc_coefficients=np.mean(librosa.feature.mfcc(y=waveform, sr=sample_rate, n_mfcc=40).T, axis=0)
    return mfc_coefficients
\end{lstlisting}
\caption[Función para calcular los espectrogramas mel de un audio]{Función para calcular los espectrogramas mel de un audio}
\label{cod:codejemplo5}
\end{code}

\begin{figure}[H]
  \centering
   % Escala la imagen al 150% de su tamaño original
  \caption{ Representación de los coeficientes MFCC de un audio.}
  \label{fig:mfcc}
\end{figure}

Como derivado de los cálculos anteriores se pueden calcular los espectrogramas mel (Figura \ref{fig:melios}) que serán otra buena función para analizar y observar más detalladamente cómo son las transiciones entre los picos de frecuencias mel. Con la función \verb|feature_melspectrogram (waveform, sample_rate)|, se consiguen las características en forma de espectrograma mel, el cual se asemeja cómo los humanos perciben las frecuencias. \texttt{N\_mels} se corresponde con el número de bandas en la escala mel con lo cual, se genera un espectrograma con 128 características y \texttt{f\_max} es la frecuencia máxima y para la mayoría de tareas de clasificación por voz, 8 kHz es suficiente. El atributo ``\texttt{.T}" transpone la matriz del espectrograma mel intercambiando así las bandas mel (filas) con los fotogramas de tiempo (columnas) y luego se calcula la media de cada columna generando así un vector de tamaño 128 en la que cada valor representa la energía media de una banda mel.

\begin{code}[H]
\begin{lstlisting}[language=Python]
def feature_melspectrogram(waveform, sample_rate):
    melspectrogram=np.mean(librosa.feature.melspectrogram(y=waveform, sr=sample_rate, n_mels=128, fmax=8000).T,axis=0)
    return melspectrogram
\end{lstlisting}
\caption[Función para calcular los espectrogramas mel de un audio]{Función para calcular los espectrogramas mel de un audio}
\label{cod:codejemplo5}
\end{code}

\begin{figure}[H]
  \centering
   % Escala la imagen al 150% de su tamaño original
  \caption{ Representación de los espectrogramas mel de un audio.}
  \label{fig:melios}
\end{figure}

Ya con todo esto se tendrían 180 características, de las cuales 128 pertenecen al número de bandas mel que se utilizan para calcular el espectrograma mel, ya que se ha establecido en 128 porque funciona óptimamente, ya que valores más altos pueden proporcionar una representación más detallada pero también pueden requerir más recursos computacionales. Otras 40 saldrían de establecer 40 \hyperlink{MFCC}{MFCC}, aunque al igual que el anterior parámetro no hay un número fijo. Las otras 12 restantes serían las del cronograma, una para cada una de las 12 clases de tonos.

Una vez calculadas las 180 características para cada uno de los audios se agruparán en una matriz los audios totales que haya en el dataset para poder representarlos correctamente de esta manera:

\begin{verbatim}
feature_matrix = np.hstack((chromagram, melspectrogram, mfc_coefficients))
\end{verbatim}

Como estas características tienen magnitudes diferentes, es necesario escalarlas para normalizar los datos y que las características tengan una escala comparable, mejorando así la estabilidad y el rendimiento del modelo, ya que se obtenía que la desviación de los coeficientes \hyperlink{MFCC}{MFCC} era mayor que la de las demás características. 

Para el escalado se usó la función \verb|StandardScaler| de sklearn que resta la media de cada característica y la divide por la desviación estándar de esa característica, produciendo características con media cero y varianza unitaria, por lo que los valores extremos tendrán menos impacto en los pesos aprendidos del modelo y el modelo será menos sensible a los valores atípicos. 

El siguiente paso sería elegir el modelo que se va a usar y como se podrá observar más adelante, se usará el modelo Random Forest para entrenar a la red, ya que en el experimento descrito en la Sección \ref{sec:eleccion_modelo}, se observó el rendimiento de cada uno de los modelos y el más fiable era el de RandomForestClassifier, junto con la clasificación por vectores de apoyo \hyperlink{SVC}{SVC} (Support Vector Classification).

El proceso final sería cargar el modelo ya entrenado, ejecutar mediante el módulo \texttt{subprocess} el comando arecord para grabar un audio, obtener las características del audio y pasárselas al modelo para que haga la predicción correcta en la respectiva clase del audio al que pertenece. El comando arecord tiene diferentes parámetros como los siguientes: 

\begin{verbatim}
arecord -t wav -d 2 -r 44000 -c 1 ej20-01-.wav 
\end{verbatim}

El parámetro -t wav especifica el tipo de archivo de audio como WAV, -d 2 establece la duración de la grabación en 2 segundos, -r establece la frecuencia de muestreo en 44,000 Hz, -c 1, especifica que se desea grabar con un solo canal (mono). Esto último es importante ya que en este caso solo se usa un canal para transmitir el sonido y si se graba como -c 2 se estará usando un canal estéreo que usa dos canales por lo que al pasárselo a la red dará problemas.

\subsection{Localización}
\label{subsec:localización}

Al navegar en interiores, la tecnología GPS no es adecuada para esta tarea ya que la señal es débil y puede proporcionar un error muy alto, por lo que se ha usado un sistema de posicionamiento basado en la utilización de balizas WiFi para obtener una estimación de la posición del robot mediante los valores \hyperlink{RSSI}{RSSI} para obtener la distancia y con la posición en la que se ubican en el mapa los \hyperlink{APs}{APs}. Para conectarse a un AP se utilizará la Función \ref{cod:codejemplo6}, en la cual se usa el comando \texttt{subprocess.run} para ejecutar \texttt{nmcli} especificando la red (en este caso WiFi), la acción para conectarse a ella junto con el nombre de la red y la contraseña y con \texttt{check=True} que hace que se genere una excepción si falla el comando.\\

\begin{code}[H]
\begin{lstlisting}[language=Python]
def connect_to_wifi(ssid, password):
    try:
        subprocess.run(["nmcli", "d", "wifi", "connect", ssid, "password", password], check=True)
        print(f"Conectado a {ssid}")
    except subprocess.CalledProcessError as e:
        print(f"Error al conectar a {ssid}: {e}")
\end{lstlisting}
\caption[Función para conectarse a una red WiFi]{Función para conectarse a una red WiFi}
\label{cod:codejemplo6}
\end{code}

Una vez se tiene la potencia recibida del AP, para calcular la distancia hay que usar la ecuación \ref{ec:ec2}:

\begin{myequation}[H]
\begin{equation}
d = 10^{\frac{A - \texttt{\hyperlink{RSSI}{RSSI}}}{10 \cdot n}}
\label{ec:ec2}
\end{equation}
\caption[Ecuación para calcular la distancia a un AP]{Ecuación para calcular la distancia a un AP}
\end{myequation} 
\texttt{Donde:}
\begin{itemize}
    \item $d$: Distancia estimada en metros.
    \item $A$: Valor \hyperlink{RSSI}{RSSI} a 1 metro del AP.
    \item \texttt{\hyperlink{RSSI}{RSSI}}: Potencia recibida.
    \item $n$: Factor de propagación (depende del entorno, generalmente es 2-3 en interiores).
\end{itemize}

Teniendo ya la distancia a cada AP y sabiendo la posición de cada uno de ellos en el mapa, mediante múltiples puntos de referencia se puede usar la trilateración y calcular la posición del robot. Para ello se puede usar el siguiente sistema de ecuaciones \ref{ec:ec5}:

\begin{myequation}[H]
\begin{equation}
\left\{
	\begin{array}{lcc}
		(x - x_1)^2 + (y - y_1)^2 = (d_1)^2\\
		(x - x_2)^2 + (y - y_2)^2 = (d_2)^2\\
		(x - x_3)^2 + (y - y_3)^2 = (d_3)^2 \\
		(x - x_4)^2 + (y - y_4)^2 = (d_4)^2
	\end{array}
\right.
\label{ec:ec5}
\end{equation}
\caption[Sistema de ecuaciones para calcular la posición dada la distancia y la posición de cada AP]{Sistema de ecuaciones para calcular la posición dada la distancia y la posición de cada AP}
\end{myequation}

El siguiente paso sería averiguar cuántos \hyperlink{APs}{APs} son necesarios para estimar la posición y que haya el mínimo de error. Para ello se realizará el experimento \ref{sec:num_aps} en el cual se comprobará esto último y también se hará un estudio sobre el impacto que tiene el espacio que hay entre las cuadrículas del mapa sobre el cálculo de la posición del robot.

\subsection{Navegación}
\label{subsec:navegación}

Un problema a tratar es la navegación, y al tener una batería tan limitada no se puede hacer que se desplace grandes distancias, por lo que se tratará la navegación en interiores. En cuanto a la navegación global, es necesario implementar un algoritmo de navegación óptimo como el de A*. Este algoritmo combina características de los algoritmos de búsqueda de coste uniforme y búsqueda heurística, lo que lo hace eficiente y efectivo en la resolución de problemas de planificación de rutas. 

Dada una lista de datos o valores, este algoritmo buscará iterativamente los datos requeridos o
valor solicitado dentro de la lista, en este caso la matriz de 0 y 1 como se mencionó anteriormente. 

Después de considerar los criterios de compensación de optimalidad, completitud, precisión y el tiempo de ejecución, se ha determinado que el algoritmo de planificación de rutas A*
sería el más adecuado para el entorno simulado que se quiere probar. 

A* es lo que se considera un algoritmo de búsqueda Best-First, lo que significa que se tomará el movimiento de menor coste por iteración. Esto significa que se elige la ruta más cercana y eficiente que sea inmediatamente visible, analizando todos los posibles caminos más cortos. A* siempre encontrará una solución si existe una, lo que lo convierte en un algoritmo de búsqueda óptimo. Este algoritmo pretende minimizar el coste del camino elegido mediante la ecuación \ref{ec:ec678}:

\begin{myequation}[H]
\begin{equation}
\left\{
	f(n) = g(n) + h(n)
\right.
\label{ec:ec678}
\end{equation}
\caption[Fórmula de la función de coste]{Fórmula de la función de coste}
\end{myequation}

Donde g(n) es el coste de cada movimiento desde el nodo inicial hasta el nodo final, y h(n) es la
heurística en la que se estiman los costes futuros. La heurística es una estimación o evaluación del coste de
movimientos futuros. Al sumar el coste estimado de los movimientos futuros y los pasos ya realizados, se puede estimar el camino de menor coste a recorrer.

El proceso final consistiría entonces en pasarle al algoritmo la imagen binaria del mapa de 0 y 1 y transformarla en una matriz con la cual trabajará el algoritmo, junto con el punto de partida y el objetivo final. Para encontrar el camino se verifica primero si el origen y el destino son válidos y si el punto inicial ya es el destino finaliza. Luego, se define la celda de inicio con los costes y la heurística a 0 dentro de otra matriz de objetos y se agrega a la cola de prioridad junto con sus coordenadas. En el bucle principal se sacará el nodo con menor f(n) de la cola de prioridad y expandiendo así el nodo con menor coste total y marcándola como visitada para no volver a procesarla. Después de esto se seguirán expandiendo los nodos vecinos y actualizando los costes y agregándolos a la cola de prioridad hasta encontrar el destino.

\begin{figure}[H]
  \centering
   % Escala la imagen al 150% de su tamaño original
  \caption{ Ejemplo de búsqueda hacia un objetivo con A*.}
  \label{fig:mel}
\end{figure}

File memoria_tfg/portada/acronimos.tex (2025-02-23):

\cleardoublepage

\chapter*{Acrónimos\markboth{Acrónimos}{Acrónimos}}

% Añade a continuación los acrónimos que uses en el documento. Algunos ejemplos:
\begin{acronym}
	\acro{GPIO}{\emph{General Purpose Input/Output}}
	\acro{HRI}{\emph{Human Robot Interaction}}
	\acro{STEM}{\emph{Science, Technology, Engineering and Mathematics}}
	\acro{ROS}{\emph{Robot Operating System}}
	\acro{DIY}{\emph{Do It Yourself}}
	\acro{CAD}{\emph{Computer-Aided Design}}
	\acro{FDM}{\emph{Fused Deposition Modeling}}
	\acro{GIMP}{\emph{GNU Image Manipulating Program}}
	\acro{APs}{\emph{Access Points}}
	\acro{PWM}{\emph{Pulse Width Modulation}}
	\acro{UART}{\emph{Universal Asynchronous Receiver-Transmitter}}
	\acro{SPI}{\emph{Serial Peripheral Interface}}
	\acro{I2C}{\emph{Inter-Integrated Circuit}}
	\acro{DoF}{\emph{Degrees of Freedom}}
	\acro{DMP}{\emph{Digital Motion Processor}}
	\acro{BLE}{\emph{Bluetooth Low Energy}}
	\acro{STFT}{\emph{Short-Time Fourier Transform}}
	\acro{MFCC}{\emph{Mel-Frecuency Cepstral Coefficients}}
        \acro{SVC}{\emph{Support Vector Classification}}
        \acro{SVM}{\emph{Support Vector Machine}}
        \acro{RBF}{\emph{Radial Basis Function}}
        \acro{RSSI}{\emph{Received Signal Strength Indicator}}
\end{acronym}

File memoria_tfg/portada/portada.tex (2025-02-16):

\thispagestyle{empty}
\vspace{2cm}

\begin{figure}[htb]
  \centerline{\resizebox{.60\textwidth}{!}{}}
\end{figure}

\begin{center}
  {\Large {\bf GRADO EN INGENIERÍA DE\\ 
                ROBÓTICA SOFTWARE}}
  \vspace{5mm}
 
  {\large {Escuela de Ingeniería de Fuenlabrada}}
  \vspace{5mm}

  {\large {Curso académico 2024-2025}}

  \vspace{1cm}

  {\large {\bf Trabajo Fin de Grado}}

  \vspace{2cm}

  {\Large {Prototipo de robot de bajo coste guiado por voz con técnicas de localización\\[1cm] }}

  \vspace{4cm}
  {\bf Tutor}: Julio Vega Pérez \\
  {\bf Autor}: Víctor de la Torre Rosa
\end{center}

\clearpage
\thispagestyle{empty}

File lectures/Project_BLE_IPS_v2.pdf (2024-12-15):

# BLE Indoor Positioning System: A Data-Driven Perspective

Azmyin Md Kamal
Graduate Student,
Department of Mechanical Engineering University of Louisiana at Lafayette Lafayette, USA
azmyin-md.kamal1@louisiana.edu

Allison Mixon
Graduate Student,
Department of Mechanical Engineering University of Louisiana at Lafayette Lafayette, USA
allison.mixon1@louisiana.edu

Abstract: BLE Indoor Positioning Systems that are implemented using propagation loss models have shown to estimate positions with large errors due to the uncertainty of RSSI signals caused by indoor obstacles and electromagnetic phenomena. To circumvent thisissue, we implemented a “fingerprinting” Indoor Positioning System which utilizes Machine Learning modelsto create a RSSI-Location map of the environment for improved location estimation. We tested our BLE IPS in four test scenarios where two different hypotheses were evaluated. The first hypothesis investigates the question: does the accuracy of Bluetooth Low Energy (BLE) IPS scale linearly with the number of beacons; the second hypothesis evaluates the question: does the accuracy increase when the minimum distance between two “fingerprint” positions is 1m while the mapping area does not change. Experimental results showed that Hypothesis 1 is true where the best accuracy obtained was 71% using 4 nodes and a Random Forest Classifier. Hypothesis 2 was proven to be true with an average accuracy of 89% achieved by a 4-node configuration using the Random Forest Classifier. Our results clearly indicate to the scalability of “fingerprinting” IPS provided the receiving device can get data from all the nodes present in the system at all possible localization points.

Index Terms—Indoor Positioning, Supervised Learning, BLE Beacons, Fingerprinting, RSSI

I. INTRODUCTION¹

he Internet of Things, more commonly referred to as IoT, is a complex system containing thousands of devices that connect to one another over the Internet [6]. Indoor positioning systems are one such IoT application which has the potential to change how people navigate indoor locations in a manner similar to GPS for outdoor locations [7]. However, GPS technology is not suitable for this task since it consumes a lot of power and can provide a maximum resolution of 5 meters whereas the required resolution of IPS systems can be as low as 1 meter [8].
The necessity for Indoor Positioning Systems (IPS) has increased greatly in the recent years due to its myriad applications such detecting the location of products stored in a warehouse, location detection of medical staff and personnel inside of a hospital, location of emergency first responders inside a building, and many more [2, 3 ,7]. There are three factors that must be taken into consideration for designing an IPS system viz. the arrangement of the receiver and transmitter, the type of RSSI analysis and the wireless technology that is used (WiFi, BLE, Zigbee, etc) [2,3].
One of the most common practice in IPS design is to estimate position using Received Signal Strength Indicator (RSSI) [3]. RSSI values can be obtained by capturing the periodic broadcast signals generated by a wireless device (WiFi, BLE Beacons). Comparing this data with a known transmitted signal strength, the propagation loss can be calculated which then can estimate position using a propagation loss model [2,3]. One of its primary drawbacks is the difficulty in choosing which propagation model (free space path loss model, Log-Distance Path Loss model, etc.) is most appropriate as their performance varies widely with indoor conditions [3,7].
Another | common | approach, | often | dubbed | the
“fingerprinting” technique, involves creating a RSSI-Location [3] map by taking repeated measurements of RSSI values at known locations. The values for each location is called a “fingerprint” [9]. A user’s position is then estimated against this “fingerprint” map. Common models used in this approach are probabilistic model, support vector classifiers, random forest classifier, kNN and so on [2,9]. Note that, this “fingerprinting” method is an application of “Supervised Machine Learning” methods [2].
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

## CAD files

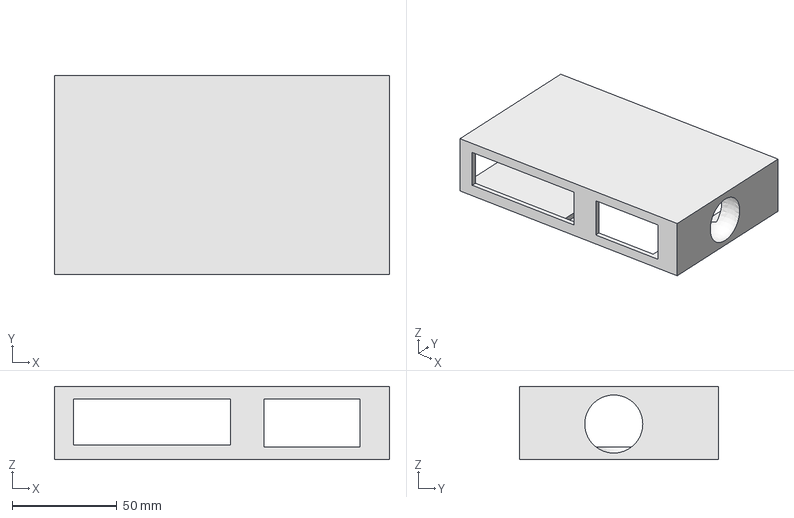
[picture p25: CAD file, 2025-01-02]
piezas/base.FCStd
160.0 x 95.0 x 35.0 mm

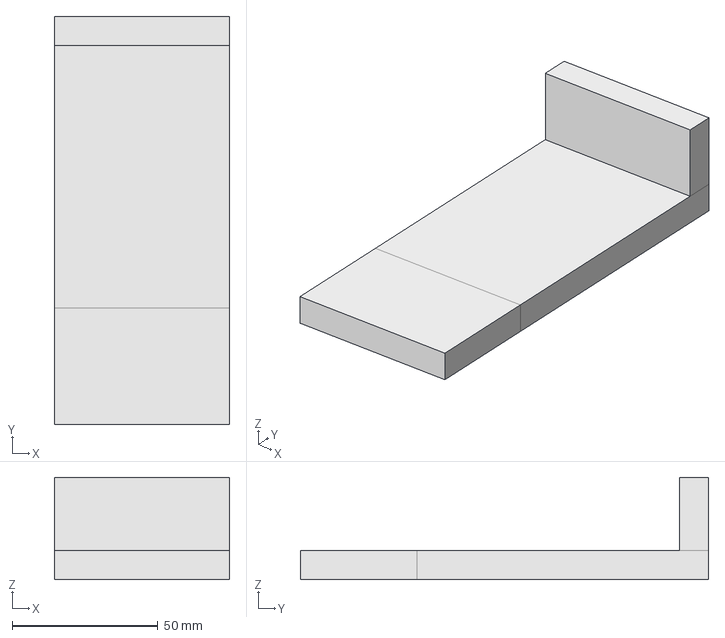
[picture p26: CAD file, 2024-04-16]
piezas/base_bateria.FCStd
60.0 x 140.0 x 35.0 mm

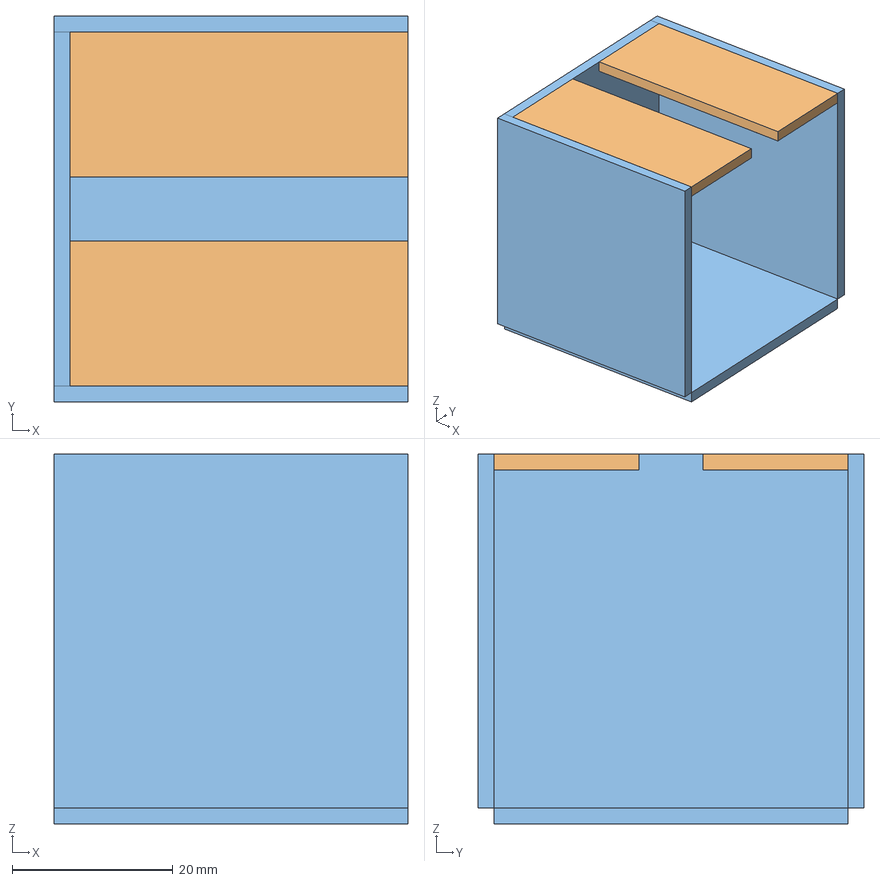
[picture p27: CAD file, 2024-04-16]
piezas/cajaaa.FCStd
44.0 x 48.0 x 46.0 mm

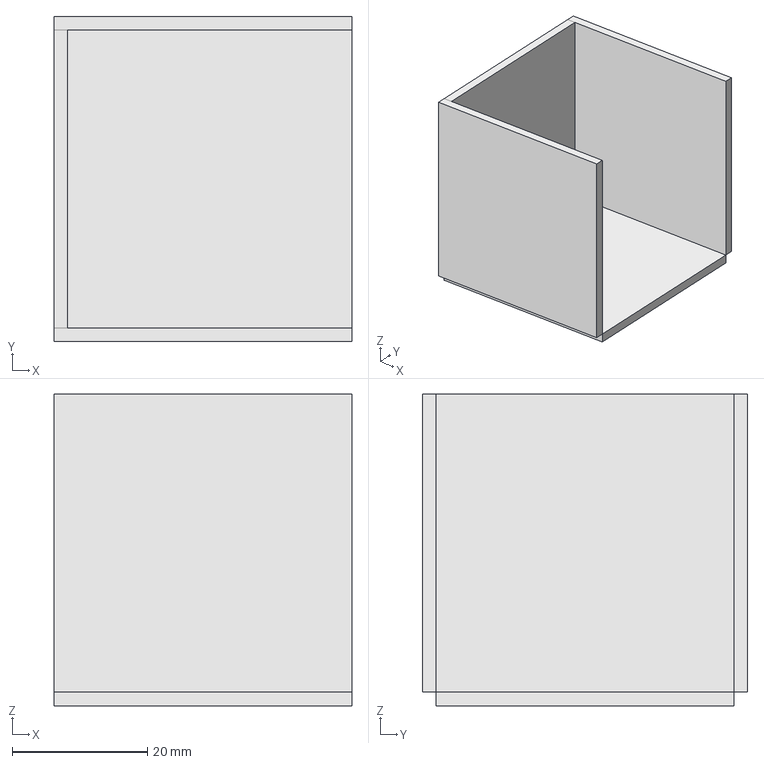
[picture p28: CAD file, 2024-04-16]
piezas/caja.FCStd
44.0 x 48.0 x 46.0 mm

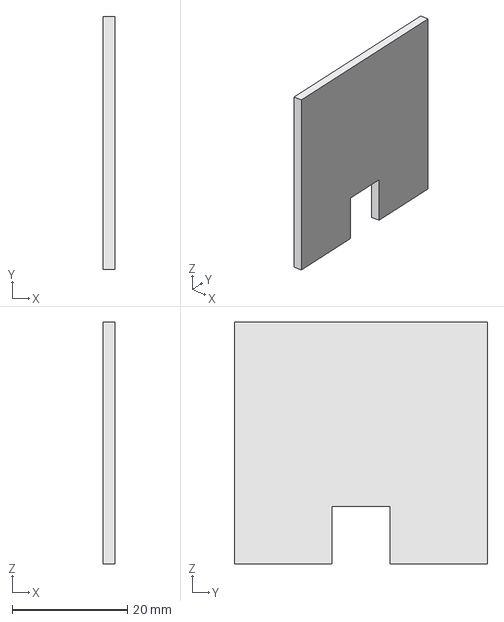
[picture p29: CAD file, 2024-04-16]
piezas/pieza_superior_apertura_cables.FCStd
2.00 x 44.0 x 42.0 mm

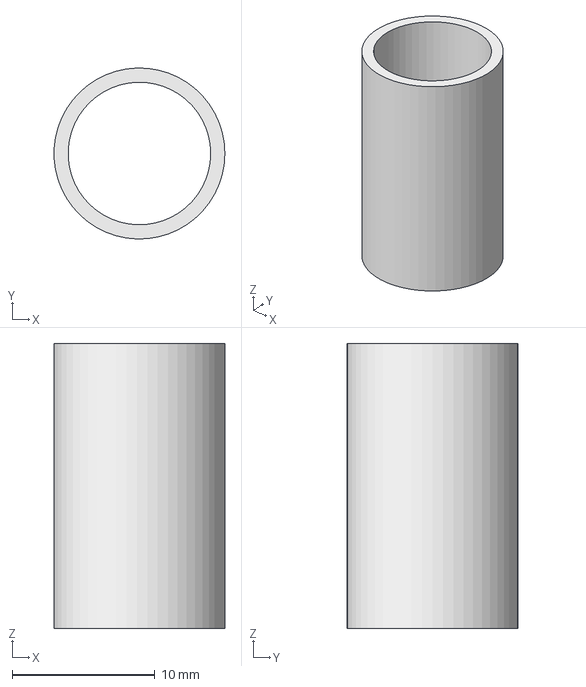
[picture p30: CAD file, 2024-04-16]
piezas/rueda.FCStd
12.0 x 12.0 x 20.0 mm

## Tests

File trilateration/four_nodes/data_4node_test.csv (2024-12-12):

B0 | B1 | B2 | B3 | Label
-53 | -46 | -32 | -49 | 1
-53 | -46 | -32 | -53 | 1
-53 | -46 | -32 | -51 | 1
-53 | -46 | -32 | -53 | 1
-53 | -46 | -32 | -55 | 1
-53 | -46 | -32 | -51 | 1
-53 | -46 | -32 | -55 | 1
-53 | -46 | -32 | -53 | 1
-53 | -46 | -32 | -54 | 1
-53 | -46 | -32 | -53 | 1
-53 | -46 | -32 | -55 | 1
-53 | -46 | -32 | -54 | 1
-53 | -46 | -32 | -55 | 1
-53 | -46 | -32 | -52 | 1
-53 | -46 | -32 | -55 | 1
-53 | -46 | -32 | -54 | 1
-53 | -46 | -32 | -54 | 1
-53 | -46 | -32 | -53 | 1
-53 | -46 | -32 | -54 | 1
-53 | -46 | -32 | -53 | 1
-52 | -45 | -44 | -48 | 2
-48 | -45 | -43 | -48 | 2
-51 | -46 | -45 | -48 | 2
-63 | -51 | -48 | -47 | 2
-55 | -50 | -46 | -50 | 2
-53 | -49 | -44 | -48 | 2
-54 | -51 | -46 | -47 | 2
-52 | -48 | -45 | -48 | 2
-53 | -52 | -47 | -48 | 2
-54 | -48 | -47 | -48 | 2
-54 | -50 | -47 | -48 | 2
-53 | -48 | -47 | -49 | 2
-53 | -48 | -46 | -48 | 2
-53 | -47 | -46 | -48 | 2
-52 | -48 | -45 | -48 | 2
-52 | -50 | -47 | -48 | 2
-52 | -50 | -46 | -48 | 2
-52 | -48 | -47 | -47 | 2
-52 | -50 | -45 | -47 | 2
-51 | -47 | -45 | -47 | 2
-57 | -43 | -46 | -54 | 3
-60 | -34 | -50 | -59 | 3
-55 | -35 | -50 | -50 | 3
-49 | -34 | -50 | -52 | 3
-52 | -34 | -50 | -50 | 3
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

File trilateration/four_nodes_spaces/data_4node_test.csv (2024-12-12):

B0 | B1 | B2 | B3 | Label
-53 | -46 | -32 | -49 | 1
-53 | -46 | -32 | -53 | 1
-53 | -46 | -32 | -51 | 1
-53 | -46 | -32 | -53 | 1
-53 | -46 | -32 | -55 | 1
-53 | -46 | -32 | -51 | 1
-53 | -46 | -32 | -55 | 1
-53 | -46 | -32 | -53 | 1
-53 | -46 | -32 | -54 | 1
-53 | -46 | -32 | -53 | 1
-53 | -46 | -32 | -55 | 1
-53 | -46 | -32 | -54 | 1
-53 | -46 | -32 | -55 | 1
-53 | -46 | -32 | -52 | 1
-53 | -46 | -32 | -55 | 1
-53 | -46 | -32 | -54 | 1
-53 | -46 | -32 | -54 | 1
-53 | -46 | -32 | -53 | 1
-53 | -46 | -32 | -54 | 1
-53 | -46 | -32 | -53 | 1
-50 | -24 | -64 | -60 | 4
-51 | -22 | -63 | -61 | 4
-49 | -23 | -64 | -55 | 4
-49 | -23 | -62 | -53 | 4
-50 | -24 | -63 | -54 | 4
-49 | -24 | -64 | -54 | 4
-49 | -24 | -62 | -53 | 4
-49 | -23 | -63 | -57 | 4
-50 | -23 | -61 | -59 | 4
-51 | -23 | -63 | -56 | 4
-50 | -23 | -62 | -53 | 4
-49 | -23 | -62 | -59 | 4
-49 | -23 | -62 | -54 | 4
-49 | -23 | -62 | -53 | 4
-49 | -23 | -61 | -53 | 4
-49 | -23 | -61 | -53 | 4
-49 | -23 | -59 | -54 | 4
-49 | -23 | -63 | -54 | 4
-50 | -23 | -61 | -53 | 4
-49 | -23 | -63 | -54 | 4
-56 | -35 | -59 | -53 | 5
-51 | -40 | -60 | -61 | 5
-47 | -40 | -54 | -58 | 5
-49 | -38 | -53 | -58 | 5
-48 | -39 | -55 | -59 | 5
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

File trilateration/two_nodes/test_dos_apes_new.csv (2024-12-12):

B0 | B1 | Label
-59 | -36 | 1
-59 | -38 | 1
-54 | -37 | 1
-60 | -39 | 1
-57 | -38 | 1
-62 | -36 | 1
-57 | -37 | 1
-61 | -37 | 1
-63 | -39 | 1
-58 | -37 | 1
-53 | -28 | 1
-50 | -29 | 1
-49 | -28 | 1
-54 | -28 | 1
-48 | -30 | 1
-51 | -29 | 1
-52 | -29 | 1
-52 | -28 | 1
-56 | -24 | 1
-56 | -24 | 1
-50 | -35 | 2
-54 | -35 | 2
-53 | -34 | 2
-52 | -37 | 2
-55 | -36 | 2
-49 | -35 | 2
-48 | -36 | 2
-53 | -34 | 2
-50 | -34 | 2
-48 | -31 | 2
-52 | -35 | 2
-50 | -35 | 2
-49 | -35 | 2
-50 | -35 | 2
-55 | -35 | 2
-57 | -35 | 2
-55 | -34 | 2
-53 | -36 | 2
-54 | -35 | 2
-54 | -36 | 2
-54 | -54 | 3
-54 | -45 | 3
-56 | -52 | 3
-59 | -46 | 3
-56 | -50 | 3
-53 | -48 | 3
-56 | -50 | 3
-56 | -50 | 3
-52 | -49 | 3
-54 | -50 | 3
-53 | -50 | 3
-50 | -53 | 3
-56 | -53 | 3
-48 | -55 | 3
-50 | -55 | 3
-49 | -56 | 3
-55 | -52 | 3
-55 | -48 | 3
-56 | -61 | 3
-57 | -62 | 3
-57 | -55 | 4
-52 | -56 | 4
-55 | -59 | 4
-52 | -59 | 4
-52 | -55 | 4
-53 | -51 | 4
-55 | -54 | 4
-50 | -58 | 4
-52 | -58 | 4
-54 | -60 | 4
-52 | -60 | 4
-59 | -51 | 4
-60 | -58 | 4
-57 | -50 | 4
-60 | -47 | 4
-59 | -51 | 4
-57 | -50 | 4
-59 | -51 | 4
-58 | -50 | 4
-60 | -59 | 4
-47 | -47 | 5
-49 | -47 | 5
-48 | -52 | 5
-46 | -48 | 5
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

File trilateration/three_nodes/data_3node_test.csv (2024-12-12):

B0 | B1 | B2 | Label
-63 | -85 | -82 | 1
-59 | -81 | -67 | 1
-64 | -67 | -80 | 1
-58 | -74 | -79 | 1
-57 | -74 | -79 | 1
-59 | -83 | -82 | 1
-60 | -74 | -82 | 1
-59 | -79 | -79 | 1
-65 | -94 | -79 | 1
-59 | -93 | -79 | 1
-53 | -81 | -80 | 1
-59 | -99 | -72 | 1
-59 | -74 | -81 | 1
-54 | -74 | -81 | 1
-59 | -81 | -86 | 1
-59 | -96 | -88 | 1
-64 | -96 | -81 | 1
-50 | -74 | -81 | 1
-58 | -92 | -79 | 1
-64 | -92 | -80 | 1
-64 | -76 | -75 | 2
-63 | -79 | -78 | 2
-65 | -80 | -62 | 2
-65 | -80 | -61 | 2
-65 | -66 | -78 | 2
-64 | -66 | -78 | 2
-64 | -78 | -78 | 2
-64 | -78 | -75 | 2
-64 | -68 | -76 | 2
-65 | -76 | -75 | 2
-65 | -79 | -78 | 2
-48 | -77 | -77 | 2
-65 | -77 | -76 | 2
-65 | -77 | -78 | 2
-63 | -76 | -76 | 2
-64 | -61 | -78 | 2
-65 | -61 | -78 | 2
-65 | -76 | -78 | 2
-65 | -78 | -79 | 2
-64 | -75 | -78 | 2
-72 | -71 | -79 | 3
-71 | -76 | -80 | 3
-57 | -76 | -66 | 3
-58 | -66 | -88 | 3
-71 | -76 | -69 | 3
-56 | -71 | -81 | 3
-68 | -60 | -83 | 3
-72 | -74 | -71 | 3
-72 | -76 | -82 | 3
-71 | -68 | -67 | 3
-72 | -51 | -69 | 3
-68 | -70 | -92 | 3
-51 | -68 | -64 | 3
-68 | -52 | -81 | 3
-67 | -59 | -90 | 3
-67 | -76 | -80 | 3
-70 | -68 | -81 | 3
-72 | -67 | -66 | 3
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

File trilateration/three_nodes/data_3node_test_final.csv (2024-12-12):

B0 | B1 | B2 | Label
-64 | -53 | -29 | 1
-57 | -55 | -28 | 1
-58 | -55 | -29 | 1
-58 | -55 | -29 | 1
-58 | -55 | -28 | 1
-57 | -53 | -29 | 1
-57 | -56 | -28 | 1
-58 | -54 | -29 | 1
-59 | -54 | -28 | 1
-58 | -55 | -28 | 1
-58 | -54 | -34 | 1
-57 | -55 | -28 | 1
-58 | -54 | -28 | 1
-57 | -54 | -29 | 1
-59 | -53 | -28 | 1
-57 | -55 | -28 | 1
-56 | -56 | -28 | 1
-57 | -55 | -29 | 1
-56 | -53 | -29 | 1
-56 | -53 | -28 | 1
-54 | -47 | -43 | 2
-55 | -46 | -43 | 2
-56 | -52 | -46 | 2
-59 | -45 | -43 | 2
-56 | -46 | -44 | 2
-56 | -46 | -44 | 2
-58 | -45 | -44 | 2
-59 | -46 | -43 | 2
-65 | -46 | -42 | 2
-55 | -46 | -43 | 2
-55 | -46 | -44 | 2
-57 | -47 | -44 | 2
-57 | -46 | -42 | 2
-56 | -46 | -43 | 2
-53 | -45 | -43 | 2
-59 | -46 | -42 | 2
-58 | -46 | -44 | 2
-62 | -45 | -41 | 2
-61 | -45 | -44 | 2
-62 | -45 | -44 | 2
-54 | -37 | -51 | 3
-55 | -36 | -51 | 3
-54 | -35 | -55 | 3
-55 | -40 | -50 | 3
-50 | -35 | -52 | 3
-55 | -41 | -57 | 3
-56 | -35 | -55 | 3
-54 | -36 | -52 | 3
-54 | -36 | -57 | 3
-54 | -36 | -55 | 3
-54 | -36 | -57 | 3
-54 | -36 | -53 | 3
-59 | -36 | -56 | 3
-57 | -36 | -53 | 3
-52 | -35 | -54 | 3
-53 | -33 | -51 | 3
-52 | -35 | -50 | 3
-52 | -35 | -50 | 3
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

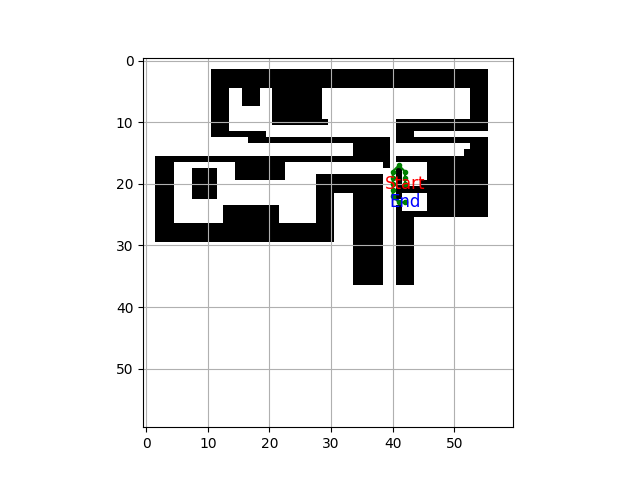
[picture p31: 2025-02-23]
final_test/astar.png

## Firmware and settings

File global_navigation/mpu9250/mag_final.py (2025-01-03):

import math
import time

from mpu9250_jmdev.mpu_9250 import MPU9250
from mpu9250_jmdev.registers import *

# Configuración del bus I2C en Raspberry Pi
bus = 1  # En Raspberry Pi, normalmente se usa el bus I2C 1

# Crear instancia del sensor
sensor = MPU9250(
    address_ak=AK8963_ADDRESS,
    address_mpu_master=MPU9050_ADDRESS_68,
    address_mpu_slave=None,
    bus=bus,
    gfs=GFS_1000,
    afs=AFS_8G,
    mfs=AK8963_BIT_16,
    mode=AK8963_MODE_C100HZ,
)

sensor.configure()  # Configurar el sensor


#sensor.calibrate()

# Variables para el filtro de paso bajo
filtered_magx, filtered_magy = 0, 0
#DECLINATION = -1 * 3.19  # Declinación magnética
DECLINATION = 0.5  # Declinación magnética
heading_angle_in_degrees = 0

# Función de filtro de paso bajo
def low_pass_filter(prev_value, new_value):
    return 0.85 * prev_value + 0.15 * new_value

# Función para obtener la dirección de la brújula
def compass(angle):
    if angle > 337 or angle <= 22:
        direction = 'North'
    elif angle > 22 and angle <= 67:
        direction = 'North East'
    elif angle > 67 and angle <= 112:
        direction = "East"
    elif angle > 112 and angle <= 157:
        direction = "South East"
    elif angle > 157 and angle <= 202:
        direction = "South"
    elif angle > 202 and angle <= 247:
        direction = "South West"
    elif angle > 247 and angle <= 292:
        direction = "West"
    elif angle > 292 and angle <= 337:
        direction = "North West"
    return direction
    

# Calibrar el magnetómetroooooooooooooooooooooooooo????????


# Bucle principal
while True:
    # Obtener los valores magnéticos
    magx_new, magy_new, _ = sensor.readMagnetometerMaster()
    #print(magx_new," ---  " ,magy_new," --- " ,_)
    magx_new = magx_new - (-19.8486328125)
    magy_new = magy_new - (73.828125)
    magz_cal = _ - (1.53)

    
    # Aplicar el filtro de paso bajo
    filtered_magx = low_pass_filter(filtered_magx, magx_new)
    filtered_magy = low_pass_filter(filtered_magy, magy_new)
    
    # Calcular el ángulo de dirección
    heading_angle_in_degrees = math.atan2(filtered_magx, filtered_magy) * (180 / math.pi)
    heading_angle_in_degrees_plus_declination = heading_angle_in_degrees + DECLINATION
    
    if heading_angle_in_degrees_plus_declination < 0:
        heading_angle_in_degrees += 360
        heading_angle_in_degrees_plus_declination += 360
    
    # Imprimir los resultados
    print('### Without Declination ###')
    print(heading_angle_in_degrees)
    #print(compass(heading_angle_in_degrees))
    #print(str(get_value()))
        
    #print('### Plus Declination ###')
    #print(heading_angle_in_degrees_plus_declination)
    #print(compass(heading_angle_in_degrees_plus_declination))
    
    # Esperar un poco antes de la siguiente lectura
    time.sleep(0.1)

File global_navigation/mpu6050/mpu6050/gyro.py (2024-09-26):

from mpu6050 import mpu6050
import time

mpu = mpu6050(0x68)


while True:
	print("Tem : " + str(mpu.get_temp()))
	print("\n")
	
	accel_data = mpu.get_accel_data()
	print("Acc X : " + str(accel_data['x']))
	print("Acc Y : " + str(accel_data['y']))
	print("Acc Z : " + str(accel_data['z']))


	gyro_data = mpu.get_gyro_data()
	print("Gyro X: "+ str(gyro_data['x']))
	print("Gyro Y: "+ str(gyro_data['y']))
	print("Gyro Z: "+ str(gyro_data['z']))

	time.sleep(1)

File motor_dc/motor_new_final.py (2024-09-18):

import RPi.GPIO as GPIO
import time
import curses


GPIO.setwarnings(False)

ena = 18
enb = 12
out1 = 20 # right coil MARRON
out2 = 26 # right coil BLANCO
out3 = 19 # left coil NEGRO
out4 = 16 # left coil ROJO

GPIO.setmode( GPIO.BCM )
GPIO.setup( ena, GPIO.OUT )
GPIO.setup( enb, GPIO.OUT )

GPIO.setup( out1, GPIO.OUT )
GPIO.setup( out2, GPIO.OUT )
GPIO.setup( out3, GPIO.OUT )
GPIO.setup( out4, GPIO.OUT )

pa = GPIO.PWM(ena,1000)
pb = GPIO.PWM(enb,1000)

pa.start(0)
pb.start(0)



def move_backward():
	pa.ChangeDutyCycle(100)
	pb.ChangeDutyCycle(100)
	for i in range(800000):
		GPIO.output( out1, GPIO.LOW )
		GPIO.output( out2, GPIO.HIGH )
		GPIO.output( out3, GPIO.LOW )
		GPIO.output( out4, GPIO.HIGH )
		
def move_forward():
	pa.ChangeDutyCycle(100)
	pb.ChangeDutyCycle(100)
	for i in range(550000):
		GPIO.output( out1, GPIO.HIGH )
		GPIO.output( out2, GPIO.LOW )
		GPIO.output( out3, GPIO.HIGH )
		GPIO.output( out4, GPIO.LOW )
		
def move_right_45():
	pa.ChangeDutyCycle(80)
	pb.ChangeDutyCycle(80)
	for i in range(365000):
		GPIO.output( out1, GPIO.LOW )
		GPIO.output( out2, GPIO.HIGH )###
		GPIO.output( out3, GPIO.HIGH )###
		GPIO.output( out4, GPIO.LOW )
		
def move_left_45():
	for i in range(350000):
		GPIO.output( out1, GPIO.HIGH )###
		GPIO.output( out2, GPIO.LOW )
		GPIO.output( out3, GPIO.LOW )
		GPIO.output( out4, GPIO.HIGH )
def stop():
	pa.ChangeDutyCycle(0)
	pb.ChangeDutyCycle(0)
	GPIO.output( out1, GPIO.LOW )
	GPIO.output( out2, GPIO.LOW )
	GPIO.output( out3, GPIO.LOW )
	GPIO.output( out4, GPIO.LOW )
	
def move_360_degrees():
	for i in range(2):
		move_right_45()
		stop()
		time.sleep(2)
		
def move_3_steps():
	for i in range(7):
		move_forward()
		stop()
		time.sleep(2)

def main():
	pa.ChangeDutyCycle(94)
	pb.ChangeDutyCycle(98)
	for i in range(700000):
		GPIO.output( out1, GPIO.LOW )
		GPIO.output( out2, GPIO.HIGH )
		GPIO.output( out3, GPIO.LOW )
		GPIO.output( out4, GPIO.HIGH )
		
	stop()
	time.sleep(2)
	
	pa.ChangeDutyCycle(94)
	pb.ChangeDutyCycle(98)
	for i in range(1200000):
		GPIO.output( out1, GPIO.LOW )
		GPIO.output( out2, GPIO.HIGH )
		GPIO.output( out3, GPIO.LOW )
		GPIO.output( out4, GPIO.HIGH )
		
	stop()
	time.sleep(2)
	
	pa.ChangeDutyCycle(94)
	pb.ChangeDutyCycle(98)
	for i in range(1200000):
		GPIO.output( out1, GPIO.LOW )
		GPIO.output( out2, GPIO.HIGH )
		GPIO.output( out3, GPIO.LOW )
		GPIO.output( out4, GPIO.HIGH )
		
	stop()
	time.sleep(2)
	
	pa.ChangeDutyCycle(94)
	pb.ChangeDutyCycle(98)
	for i in range(1200000):
		GPIO.output( out1, GPIO.LOW )
		GPIO.output( out2, GPIO.HIGH )
		GPIO.output( out3, GPIO.LOW )
		GPIO.output( out4, GPIO.HIGH )
		
	stop()
	time.sleep(2)
	
	pa.ChangeDutyCycle(94)
	pb.ChangeDutyCycle(98)
	for i in range(1200000):
		GPIO.output( out1, GPIO.LOW )
		GPIO.output( out2, GPIO.HIGH )
		GPIO.output( out3, GPIO.LOW )
		GPIO.output( out4, GPIO.HIGH )
		
	stop()
	time.sleep(2)

	

	
def cleanup():
    #enb??
    pa.stop()
    pb.stop()
    GPIO.output( [out1,out2,out3,out4, ena,enb], GPIO.LOW )
    GPIO.cleanup()

main()        
cleanup()

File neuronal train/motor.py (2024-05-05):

#!/usr/bin/python3
import RPi.GPIO as GPIO
import time

enb = 23
out1 = 17 #right coil MARRON
out2 = 18 #right coil BLANCO
out3 = 27 # left coil NEGRO
out4 = 22 # left coil ROJO

#1.195
DEG_PER_STEP = 0.9
STEP_PER_REVOLUTION = int(360 / DEG_PER_STEP)

#delay btw steps
delay = 0.003

#500 steps for 180 degrees

GPIO.setwarnings(False)

 
# setting up
GPIO.setmode( GPIO.BCM )
GPIO.setup( [out1,out2,out3,out4,enb], GPIO.OUT )


pb = GPIO.PWM(enb,100)

pb.start(100)



 
# initializing
GPIO.output( out1, GPIO.LOW )
GPIO.output( out2, GPIO.LOW )
GPIO.output( out3, GPIO.LOW )
GPIO.output( out4, GPIO.LOW )
 
 
def cleanup():
    #enb??
    GPIO.output( [out1,out2,out3,out4], GPIO.LOW )
    GPIO.cleanup()
    
   
def move_cw():
    for _ in range(STEP_PER_REVOLUTION):
        GPIO.output( [out1,out2,out3,out4], [GPIO.LOW,GPIO.LOW,GPIO.LOW,GPIO.HIGH] )
        time.sleep(delay)
        GPIO.output( [out1,out2,out3,out4], [GPIO.LOW,GPIO.HIGH,GPIO.LOW,GPIO.LOW] )
        time.sleep(delay)
        GPIO.output( [out1,out2,out3,out4], [GPIO.LOW,GPIO.LOW,GPIO.HIGH,GPIO.LOW] )
        time.sleep(delay)
        GPIO.output( [out1,out2,out3,out4], [GPIO.HIGH,GPIO.LOW,GPIO.LOW,GPIO.LOW] )
        time.sleep(delay)
    

def move_ccw():
    for _ in range(STEP_PER_REVOLUTION):
        GPIO.output( [out1,out2,out3,out4], [GPIO.HIGH,GPIO.LOW,GPIO.LOW,GPIO.LOW] )
        time.sleep(delay)
        GPIO.output( [out1,out2,out3,out4], [GPIO.LOW,GPIO.LOW,GPIO.HIGH,GPIO.LOW] )
        time.sleep(delay)
        GPIO.output( [out1,out2,out3,out4], [GPIO.LOW,GPIO.HIGH,GPIO.LOW,GPIO.LOW] )
        time.sleep(delay)
        GPIO.output( [out1,out2,out3,out4], [GPIO.LOW,GPIO.LOW,GPIO.LOW,GPIO.HIGH] )
        time.sleep(delay)
    
'''
move_cw()

pb.ChangeDutyCycle(90)
time.sleep(1)
move_ccw()  
'''
  
'''
# the meat
try:
    i = 0
    for i in range(500):
        if i%4==0:
            GPIO.output( out4, GPIO.HIGH )
            GPIO.output( out3, GPIO.LOW )
            GPIO.output( out2, GPIO.LOW )
            GPIO.output( out1, GPIO.LOW )
        elif i%4==1:
            GPIO.output( out4, GPIO.LOW )
            GPIO.output( out3, GPIO.LOW )
            GPIO.output( out2, GPIO.HIGH )
            GPIO.output( out1, GPIO.LOW )
        elif i%4==2:
            GPIO.output( out4, GPIO.LOW )
            GPIO.output( out3, GPIO.HIGH )
            GPIO.output( out2, GPIO.LOW )
            GPIO.output( out1, GPIO.LOW )
        elif i%4==3:
            GPIO.output( out4, GPIO.LOW )
            GPIO.output( out3, GPIO.LOW )
            GPIO.output( out2, GPIO.LOW )
            GPIO.output( out1, GPIO.HIGH )
 
        time.sleep( delay )
 
except KeyboardInterrupt:
    cleanup()
    exit( 1 )

 
cleanup()
exit( 0 )
'''

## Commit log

2024-02-15 hoja motor
2024-04-22 imagen raspberry 3 vs 4
2024-05-05 codigo motores
2024-08-28 code new motor
2024-09-26 image gyro
2024-10-03 test gyro
